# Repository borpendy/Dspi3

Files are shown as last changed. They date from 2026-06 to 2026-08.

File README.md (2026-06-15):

# DSpi3
<div align="center">
  Lower DSpi
</div>

# System overview
The DSpi3 is the 3rd generation of the DS-pi project, a project with the goal of creating an open source dual screen gaming handheld, aimed at DS and 3DS emulation. This iteration features a full outer redesign, with significant reductions in width, as well as a fully redesigned cooling system. The screen configuration has also been upgraded again, now featuring dual 720p displays.

# Emulation capabilities
System performance is as expected from a standard raspberry pi 5. The system should be able to confortably emulate DS, PS1, PSP and any systems below that. I have also had good results with 3ds emulation, using the Borked3DS emulator, and some light PS2 and GC games may be playable. Regular steam also works, using the box86 and wine translation layers, however the number of playable games is limited. Streaming games should also be possible via steam-link or any other streaming methods.

# System Specifications

- Uses any Pi CM5 module (however the CM5 lite 8GB wifi is highly recommended) with 4 A76 cores at 2.4GHz.
- Duak 1280x720 5 inch displays, with capacitive touch on both screens.
- Stereo speakers, using PCM5102 DAC + NS4150B amplifier, over the I2S interface.
- Headphone output, sharing the same PCM5102 DAC + PAM8908 Headphone AMP, speaker muting is enabled through the 3.5mm jack.
- 5000 Mah LiPo battery, with USB-PD charging enabled using the BQ24192 1S BMS, and HUSB238 PD controller..
- Full size controller using RP2040, and the GP2040CE firmware, using dual analog 3ds slide pads.
- Full 3d printable chassis, with both FDM and resin options available, using GBA SP hinges.

In addition to the changes in spec, this generation has also undergone a complete redesign of the internal electronics, to make use of the Modu-PI motherboard, more information here: https://github.com/borpendy/Modu-PI. This allows for a degree of seperation between the main motherboard, and controller daughterboard. If anyone wants to have a shot at improving the controller board (IMU, RGB ect), this should make things way easier for you.

## Other notes
Again this project is experimental, and not all things will work perfectly. This project has been an interesing journey, but unless you really want a linux handheld, I would suggest buying a current android handheld. If you are interested in how these devices are designed however, I encourage you check out the schematics above. Most of all, this has been fun, and its cool to have total freedom to design something yourself, and if you're thinking about doing someting similar, I highly recommend the experience.

Note: This ones internally very similar to the dspi 2 so I reused some of the description :)

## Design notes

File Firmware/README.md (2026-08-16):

# Board firmware
The DSPI motherboard requires programming of the onboard stm32 microcontroller before use. This can be done using any ST-LINK programmer, and the provided programming pins on the motherboard.\
\
To program the board, download the STM32CUBE project file above and run with the board connected through the ST-LINK as below:

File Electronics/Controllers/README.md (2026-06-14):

# Custom Controllers
These are based on the GP2040CE advanced breakout, and use the GP2040CE firmware. To program the boards, follow the GP2040CE installation instructions. The controller is connected to the motherboard over a standard usb interface, and should act as a standard usb controller.

Note for ordering: The impedance requirements for the pcb should be fairly loose, but to be safe I recommend using the JLC 7628 stackup when ordering the boards.

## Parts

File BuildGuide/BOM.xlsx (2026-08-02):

Part | Part name | Price | Sourcing
Main screen | Waveshare 5-DSI-TOUCH-A | 52.7 | https://www.waveshare.com/5-dsi-touch-a.htm
Secondary screen | Waveshare 5-DSI-TOUCH-A | 53.7 | https://www.waveshare.com/5-dsi-touch-a.htm
Raspberry pi cm5 | SC1598 (8GB lite wireless) | 276 | https://www.digikey.com.au/en/products/detail/raspberry-pi/SC1598/25805587
Battery | 955565 LIPO | 9 | https://www.amazon.com.au/dp/B0BG82T39Y
Fan | Rasberry pi blower 30x30x7 | 5 | https://www.aliexpress.com/item/1005006547048892.html
Heatsink | Aluminium Heatsink for CM4 | 5 | https://www.waveshare.com/cm4-heatsink.htm
Motherboard | Custom build - JLCPCB | ??? | https://github.com/borpendy/Dspi3
Controller Left | Custom build - JLCPCB | ??? | https://github.com/borpendy/Dspi3
Controller Right | Custom build - JLCPCB | ??? | https://github.com/borpendy/Dspi3
Thumbstick x2 | 3DS slidepad | 12x2 | https://www.aliexpress.com/item/1005005449043551.html
mobo to controller cable | 100mm 22p dsi ribbon cable (forward direction) | 7 | https://www.aliexpress.com/item/1005006608534110.html
controller interconnect cable | 150mm 22p dsi ribbon cable (forward direction) | 7 | https://www.aliexpress.com/item/1005006608534110.html
screen 1 cable | 100mm 22p dsi cable (reverse) (comes with screen) | 0 | N/A
screen 2 cable | 300mm 22p dsi cable (reverse) | 10 | https://www.aliexpress.com/item/1005006608534110.html
Screens power cable | Custom (need 2p jst ph2.0 cable) | 3 | https://www.aliexpress.com/item/1005007617385129.html
face buttons (if installing by self) | 6x6x3.1mm push button red | 5 | https://www.aliexpress.com/item/1005008012010102.html
back buttons (if installing by self) | 6x6x4.3mm push button right angle | 2 | https://www.aliexpress.com/item/1005010093330224.html
Any sd card
Speakers x2 | SP-1605 | 7 | https://www.digikey.com.au/en/products/detail/soberton-inc/SP-1605/3973691
Speaker wires | jst sur 2p 0.8mm 200mm | 3 | https://www.aliexpress.com/item/1005009264311917.html
Screw kit machine screws |  |  | https://www.amazon.com.au/dp/B0B394XZD3
Screw kit self taping |  |  | https://www.amazon.com.au/dp/B0D4QLWSBK
Jst connector right angle | Right-Angle JST Socket Male Connector |  | https://www.aliexpress.com/item/33053313994.html

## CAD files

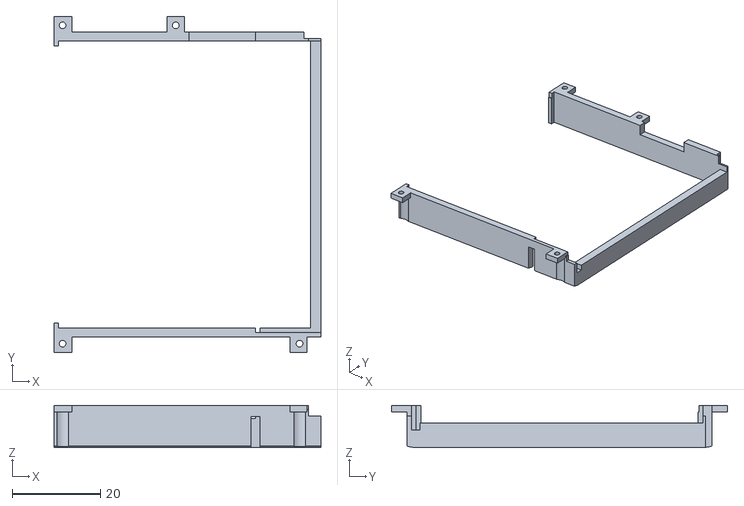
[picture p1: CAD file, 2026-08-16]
Print files/BodyParts/battery holder.stl
60.3 x 76.0 x 9.50

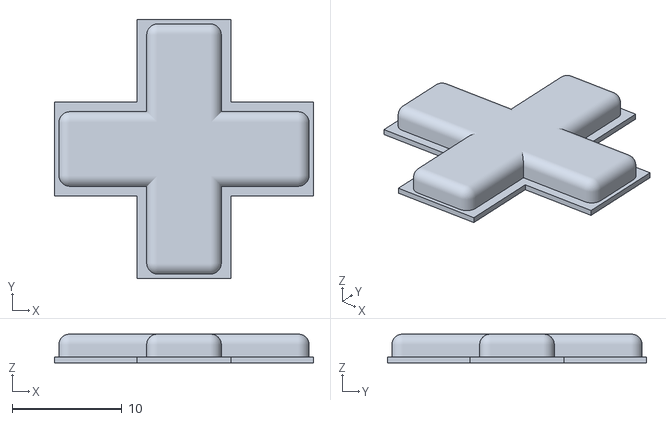
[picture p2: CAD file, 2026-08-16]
Print files/Buttons/dpad.stl
23.6 x 23.6 x 2.61

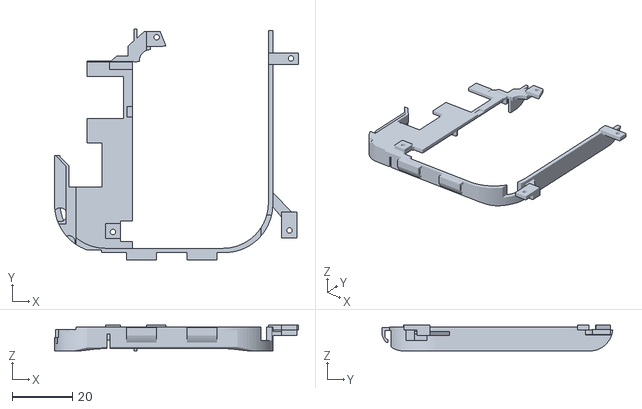
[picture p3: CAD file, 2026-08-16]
Print files/BodyParts/fan mount.stl
80.8 x 76.4 x 8.60

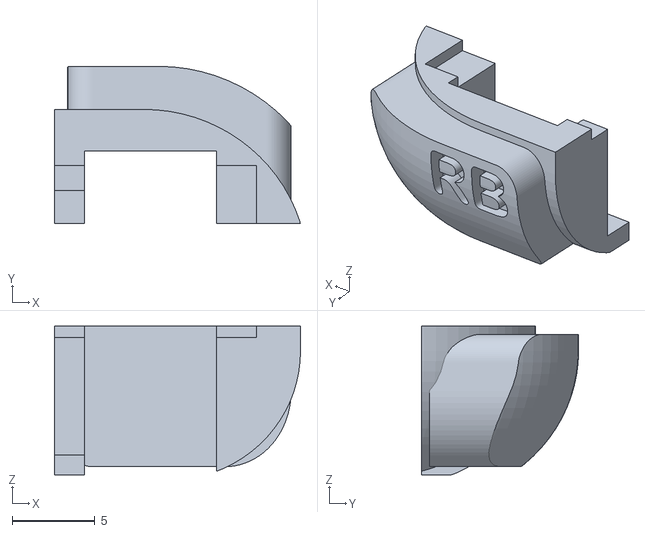
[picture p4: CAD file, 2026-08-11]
Print files/Buttons/RB.stl
14.9 x 9.50 x 9.00

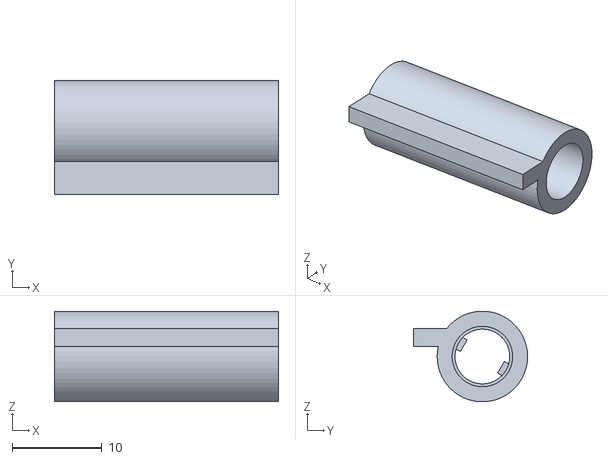
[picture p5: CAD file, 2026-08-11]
Print files/BodyParts/hinge_r_outer.stl
25.0 x 12.7 x 10.1

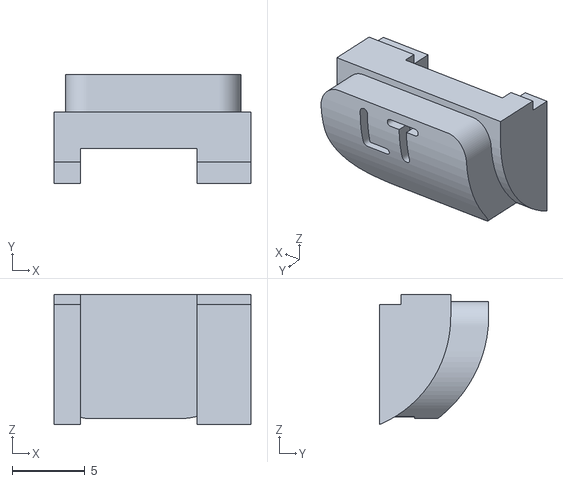
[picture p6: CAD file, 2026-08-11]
Print files/Buttons/LT.stl
13.5 x 7.50 x 8.92

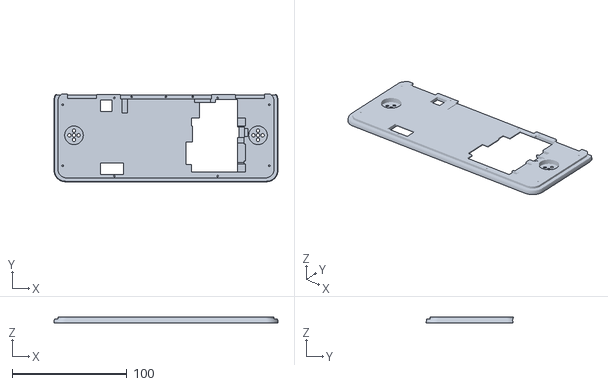
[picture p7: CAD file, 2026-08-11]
Print files/BodyParts/top plate.stl
195.0 x 76.3 x 5.40

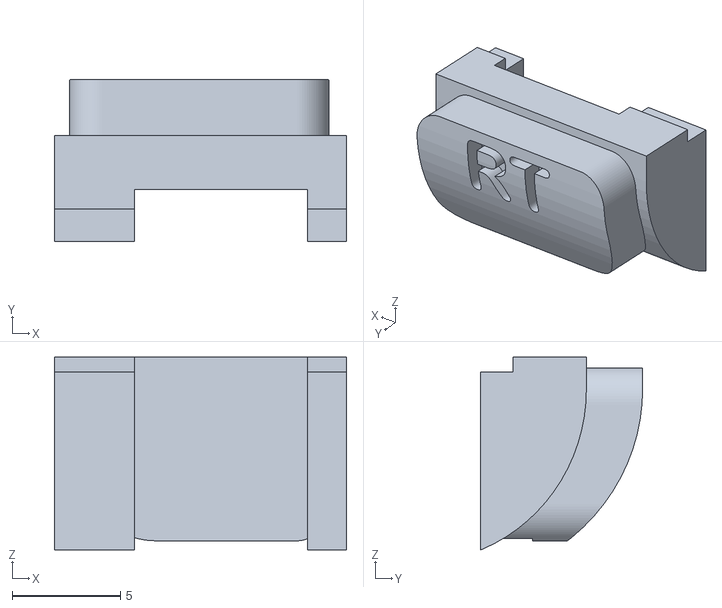
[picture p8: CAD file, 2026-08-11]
Print files/Buttons/RT.stl
13.5 x 7.50 x 8.92

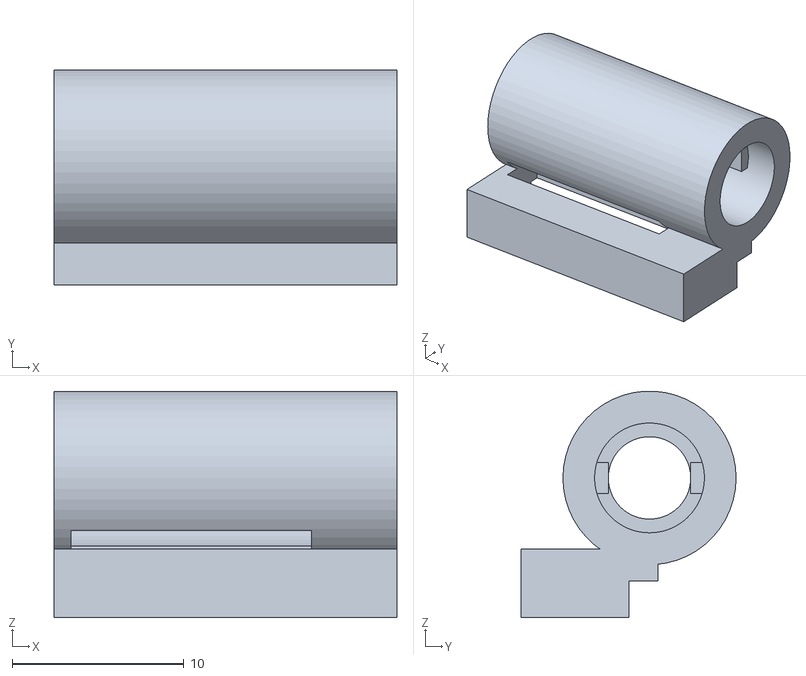
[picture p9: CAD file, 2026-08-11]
Print files/BodyParts/hinge_r_inner.stl
20.0 x 12.6 x 13.2

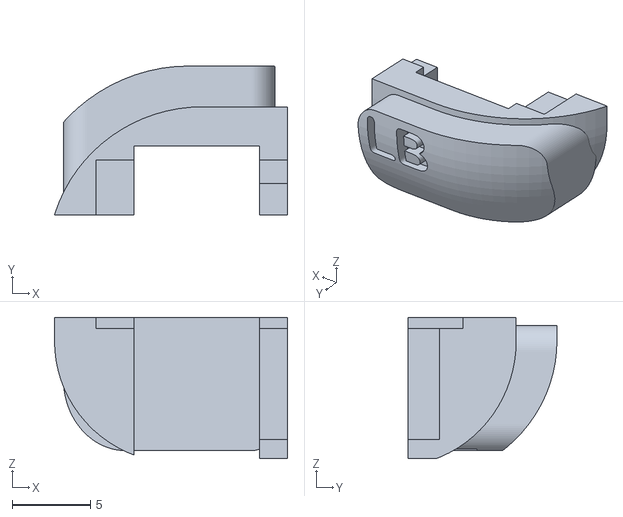
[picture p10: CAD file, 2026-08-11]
Print files/Buttons/LB.stl
14.9 x 9.50 x 9.00

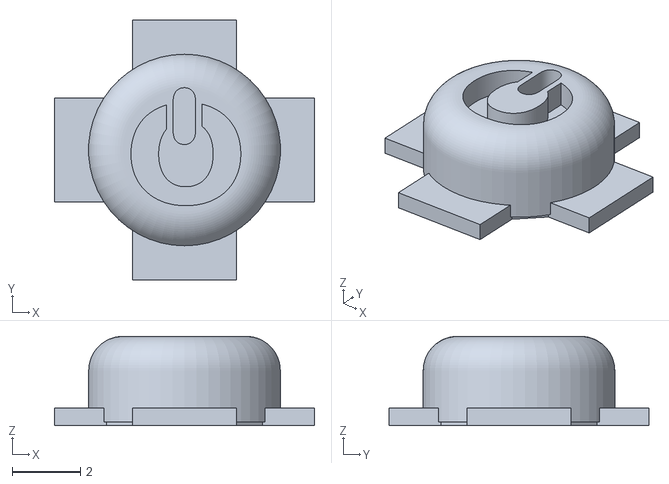
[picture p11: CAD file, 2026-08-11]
Print files/Buttons/PWR.stl
7.60 x 7.60 x 2.61

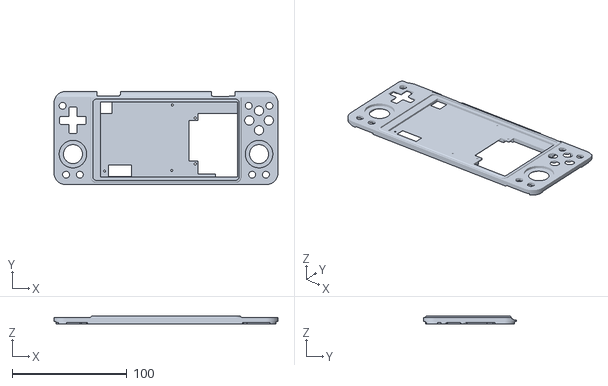
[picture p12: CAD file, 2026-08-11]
Print files/BodyParts/bottom plate.stl
195.0 x 81.0 x 6.73

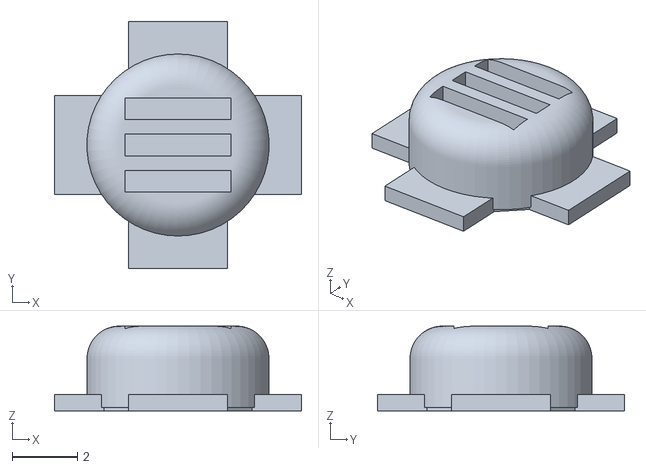
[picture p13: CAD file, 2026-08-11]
Print files/Buttons/SELECT.stl
7.60 x 7.60 x 2.61

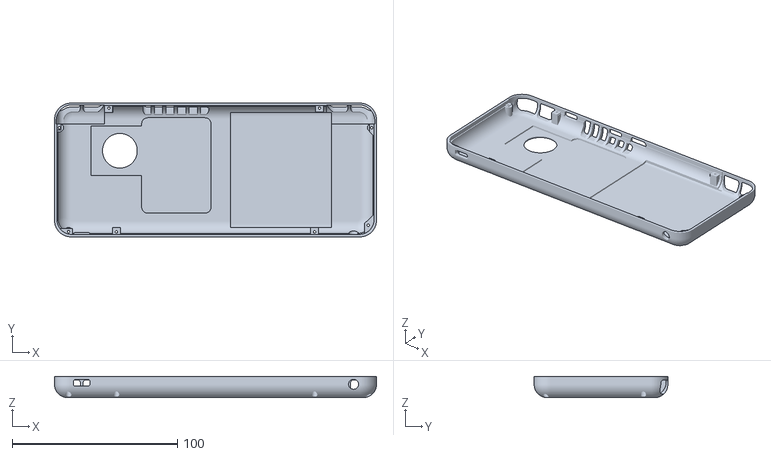
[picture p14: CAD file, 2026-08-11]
Print files/BodyParts/bottom cover.stl
195.0 x 81.0 x 12.9

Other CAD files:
Print files/BodyParts/hinge_l_outer.stl
Print files/Buttons/START.stl
Print files/BodyParts/top cover.stl
Print files/Buttons/A.stl
Print files/BodyParts/hinge_l_inner.stl
Print files/BodyParts/hinge_m.stl
Print files/Buttons/B.stl
Print files/Buttons/LS.stl
Print files/Buttons/X.stl
Print files/Buttons/Y.stl
dspi final.blend

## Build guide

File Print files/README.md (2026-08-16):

# Print parts
You can find all the stl's required to print your own parts here. Note that there are seperate shell files for resin and filament printers. This is as the hinge parts must be printed seperatly using filament, to maintain acceptable strength and dimensional accuracy. 
The internal parts may be printed in resin or fdm. I personally prefer fdm for the holders, and resin for the buttons.

When printing make sure you scale appropriately for the material used, I had good results using 100.3% scale for pla. Also scale all buttons at 98% before printing.

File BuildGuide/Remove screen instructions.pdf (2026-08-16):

## How to remove Waveshare 5 inch screen from enclosure:

Step 1: Get a hotplate/FDM printer plate, set the plate temp to 80 degrees Celsius and place the screen face down on the plate. Make sure the screws on the back of the screen case have been removed:

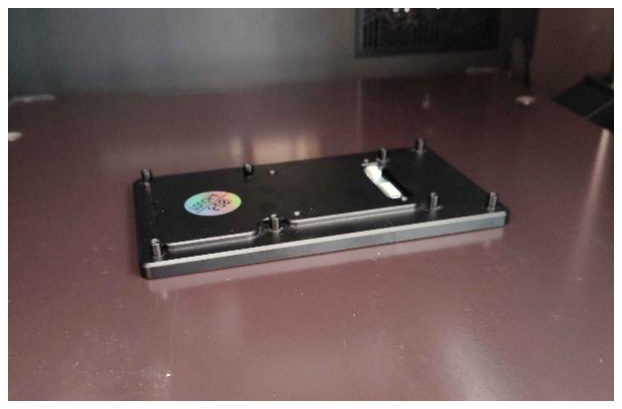
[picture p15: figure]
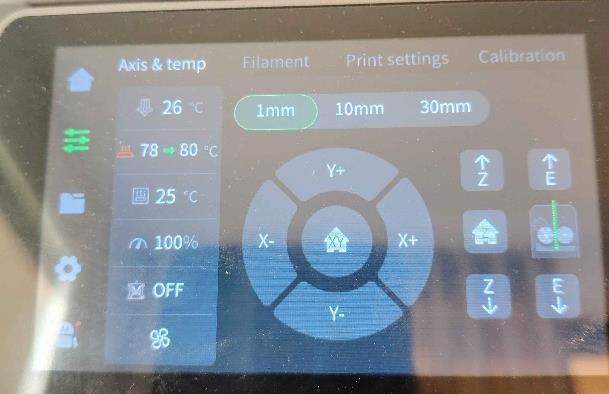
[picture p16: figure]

Step 2: Once the back of the screen feels hot, remove the screen and push it from behind, just above the power and data connectors, using your fingers.

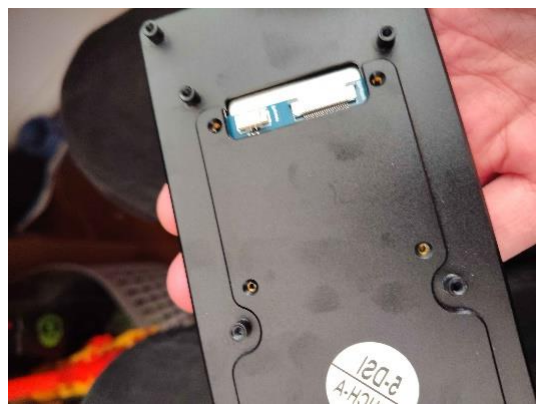
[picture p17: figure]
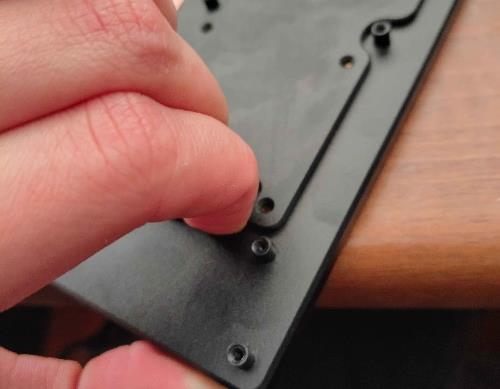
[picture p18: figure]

Step 3: If done correctly, there should now be a small gap at the edge of the screen when pushing. Put either your nail or a small plastic shim in here and push it lengthways to widen the gap. Move around the edge of the screen and it should eventually come out:

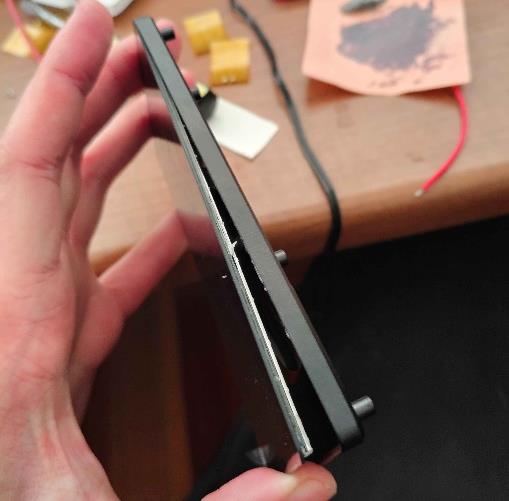
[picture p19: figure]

Authors note: This step is really annoying, and this process is probably the hardest part of the build. If anyone finds a better way to do this, please let me know.

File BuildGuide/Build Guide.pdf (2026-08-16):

# DSpi3 Build guide

By William Oprey :)

Please note:
This is an intermediate to difficult level project. To build this, you must know how to solder at minimum, and there is some fiddly work that may be difficult for some people. You also need either an FDM or Resin printer to produce parts, and having an FDM printer is useful for the screen removal as well.
I haven’t included any instructions for this, but I highly recommend some post processing + painting of the main parts before assembly, as it looks quite nice.

Parts list:
Part | Quantity
RasPI 5 Compute module lite | 1
DSPI Motherboard | 1
DSPI Left controller board | 1
DSPI Right controller board | 1
Bottom Plate Print | 1
Bottom Cover Print | 1
Lower Hinge Right Print | 1
Lower Hinge Left Print | 1
Lower Hinge Middle Print | 1
Fan Guide Print | 1
Battery Holder Print | 1
Top Plate Print | 1
Top Cover Print | 1
Top Hinge Left Print | 1
Top Hinge Right Print | 1
PCB Inserts Print | 1
Buttons Prints | 1
Waveshare 5 -DSI -TOUCH -A screen | 2
GBA SP Hinge | 2
Soberton SP -1605 Speakers | 2
3DS Thumbstick (inc cap) | 2
Raspberry pi 5 fan 30x30 | 1
Pi CM5 low -profile heatsink | 1
5000maH 955565 LiPo battery | 1
15cm 22p same side ribbon cable | 1
30cm 22p opposite side ribbon cable | 1
10cm 22p same side ribbon cable | 1
10cm 22p opposite side ribbon cable | 1
JST PH 2.0 2p cable | 2
JST PH 1.25 2p cable | 2
JST SUR 0.8 2p cable | 2
M1.7x4 machine screw | 20
M1.7x8 self -taping screw | 4
M1.7x3 machine screw | 11
M2x5 machine screw | 4
6x6x3.1 tactile pushbutton | 15
JST 2.0 header right angle | 2

Build steps:
Step 1:
Apply super glue to the hinge cutouts on the top and bottom plates, then attach the outer and inner hinges to their respective plates:
Step 2:

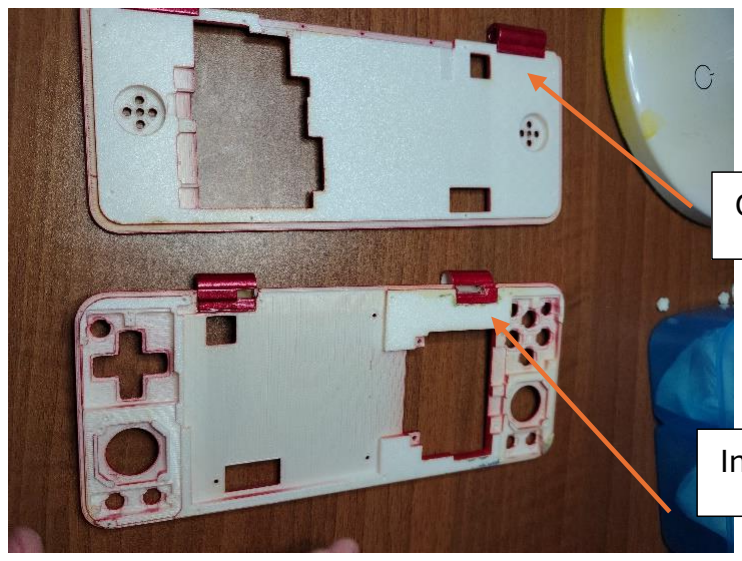
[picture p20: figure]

Remove the screens from the metal enclosures they come in, steps for this are in a separate file on the GitHub
Step 3:
Insert the screens into the top and bottom plates, then apply hot glue into the cutouts provided. Ensure the hot glue does not protrude out from the plate, so the pcbs mount correctly later.
Step 4:

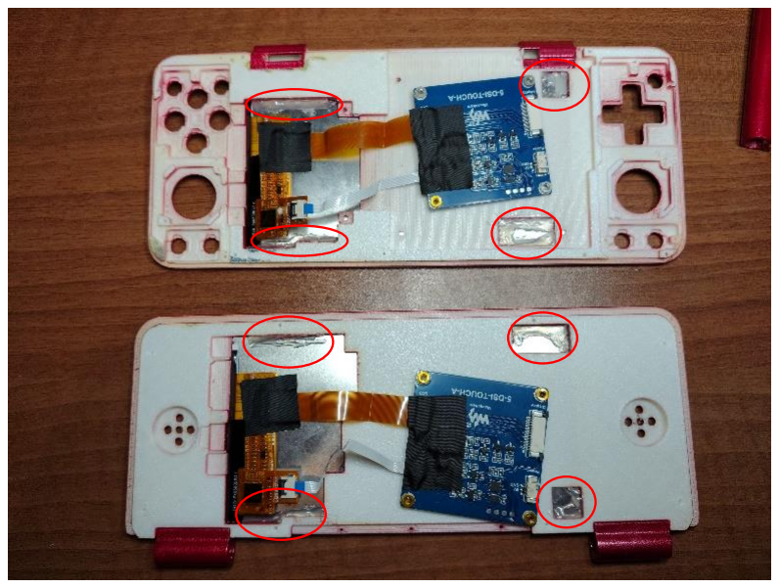
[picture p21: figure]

Insert the GBA hinges into the outer hinge on the top plate. Ensuring the hinge is aligned to the guides in the body, such as in the image below:

Outer hinges

Inner hinges

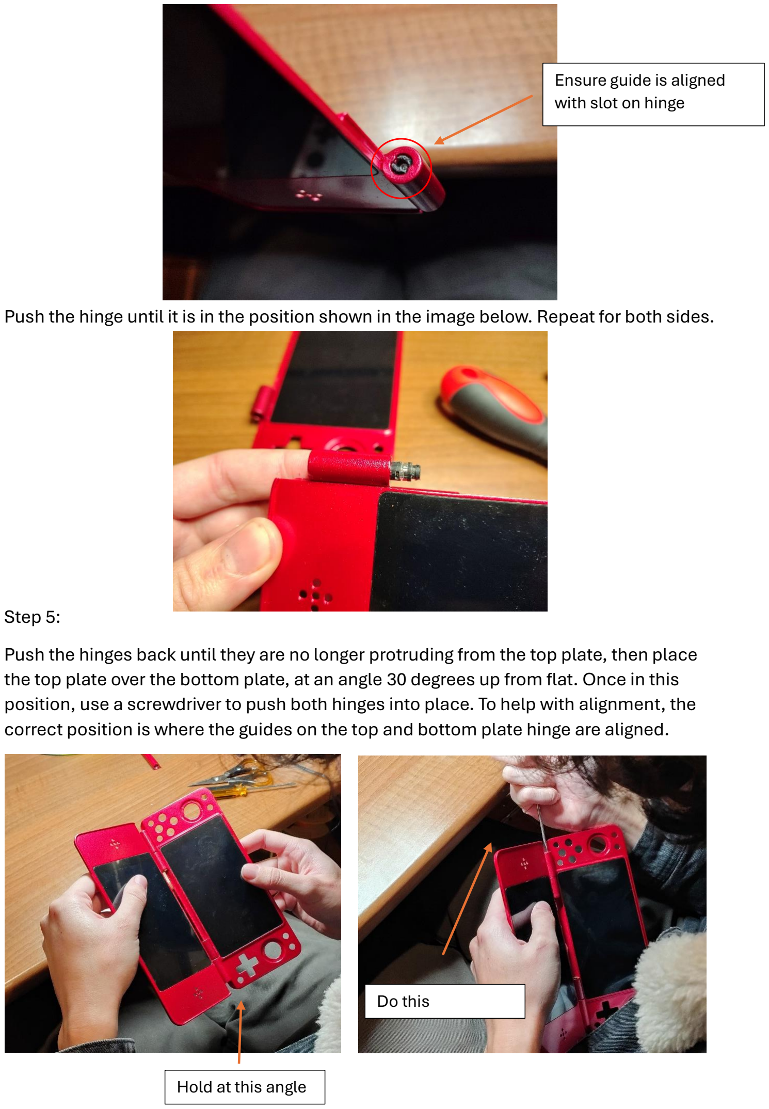
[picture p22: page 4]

Push the hinge until it is in the position shown in the image below. Repeat for both sides.

Step 5:
Push the hinges back until they are no longer protruding from the top plate, then place the top plate over the bottom plate, at an angle 30 degrees up from flat. Once in this position, use a screwdriver to push both hinges into place. To help with alignment, the correct position is where the guides on the top and bottom plate hinge are aligned.

Ensure guide is aligned
with slot on hinge

Hold at this angle

Do this

Step 5:
Secure the screen PCB to the bottom plate using the original screws from the screen case. Only screw in the screws shown in the picture below.
Step 6:

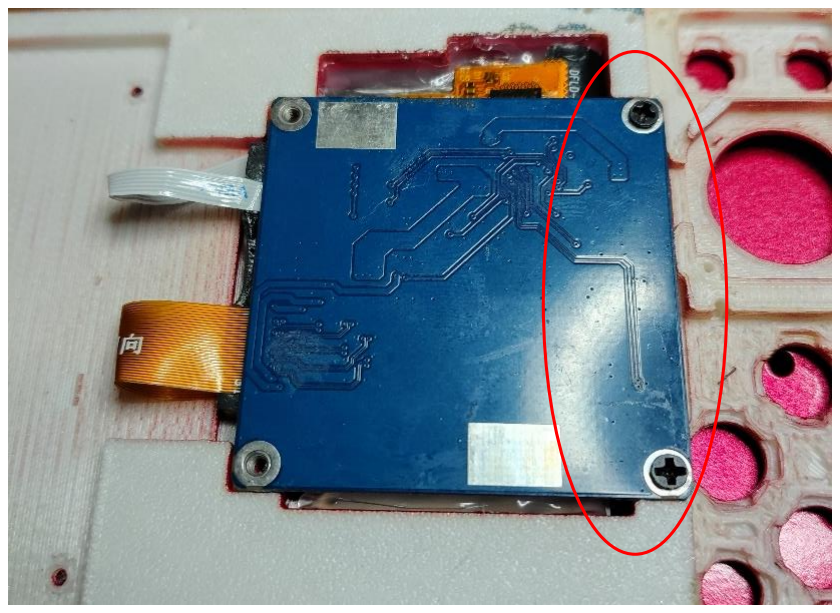
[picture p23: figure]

Get the screen PCB inserts (3D Print) and place them over the standoffs on the upper screen PCB. Place the PCB over the top plate with inserts in the provided slots, then superglue the inserts into place.

Step 7:

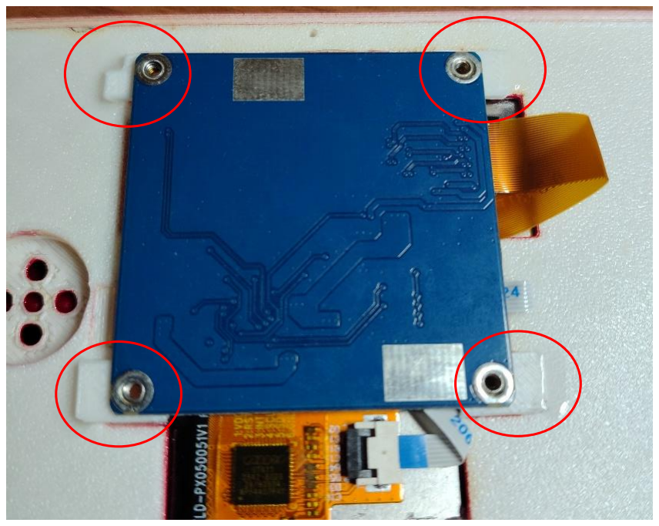
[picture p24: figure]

Place the front facing buttons into the plate. Ensure that all buttons go fully into place, if any get stuck before this you may have to use a screwdriver to clear out the button guide tabs.

Step 8:

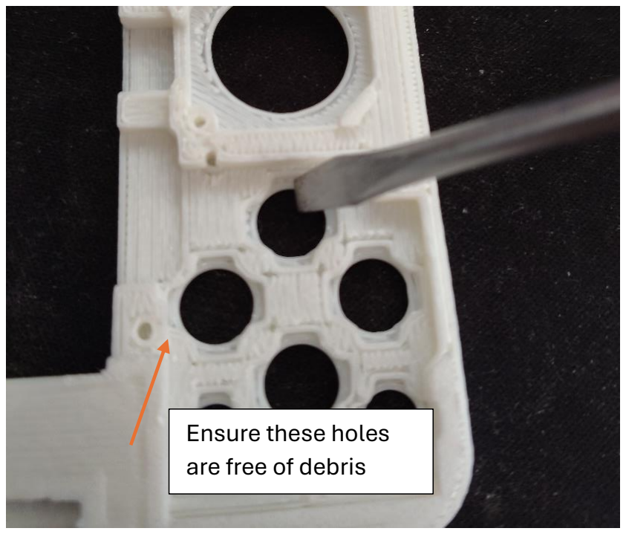
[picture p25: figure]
Ensure these holes are free of debris

Solder the buttons to the controller PCBs. Ensure that you solder the bumper buttons first, then use clippers to remove any protruding pins, before soldering the face buttons.
Step 9:
Screw in the left and right controller PCBs to the bottom plate. Test all the buttons once PCBs are inserted, there should be a click sound and feel. Insert the thumb stick FPC cables into their connectors and screw the thumb sticks to the plate. Connect the PCBs together using a 22p 15cm same side ribbon cable.
Use m1.7x4 machine screws for the PCBs and m1.7x8 self-taping screws for the sticks

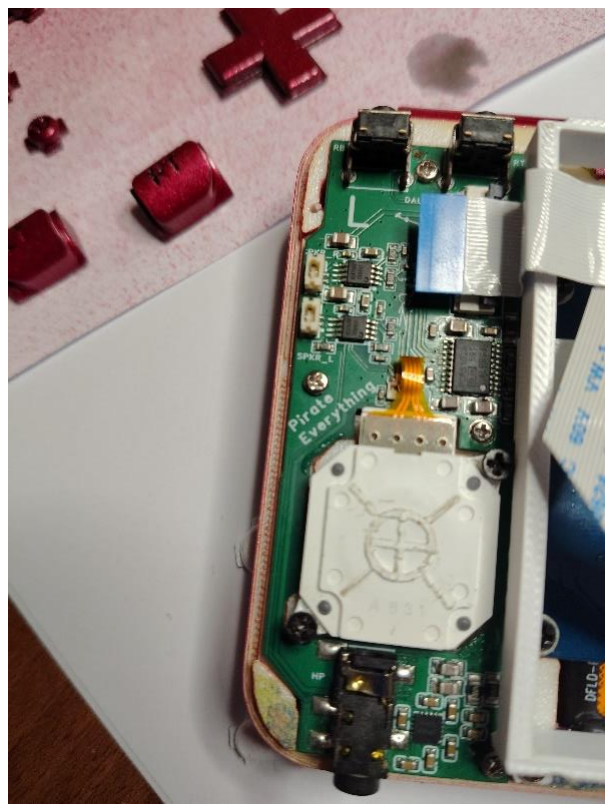
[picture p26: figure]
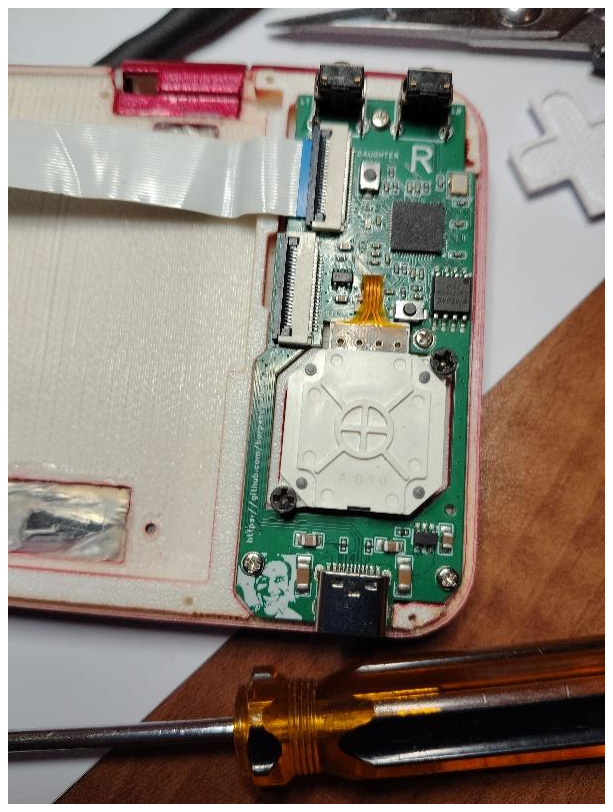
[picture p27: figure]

Step 10:
Roll a 30cm 22p different side ribbon cable through the left hinge, using the provided hole. Ensure the orientation of the cable matches the one pictured

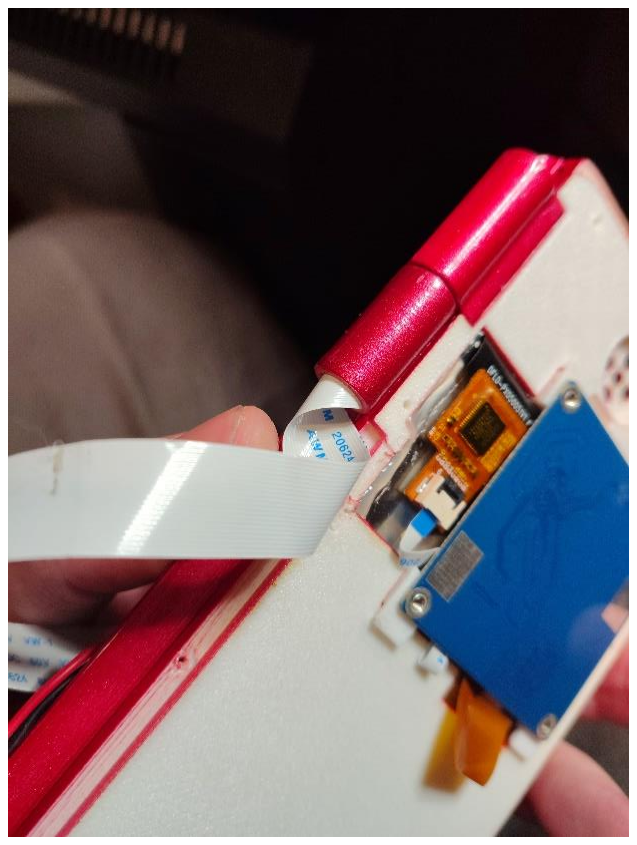
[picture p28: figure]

Step 11:

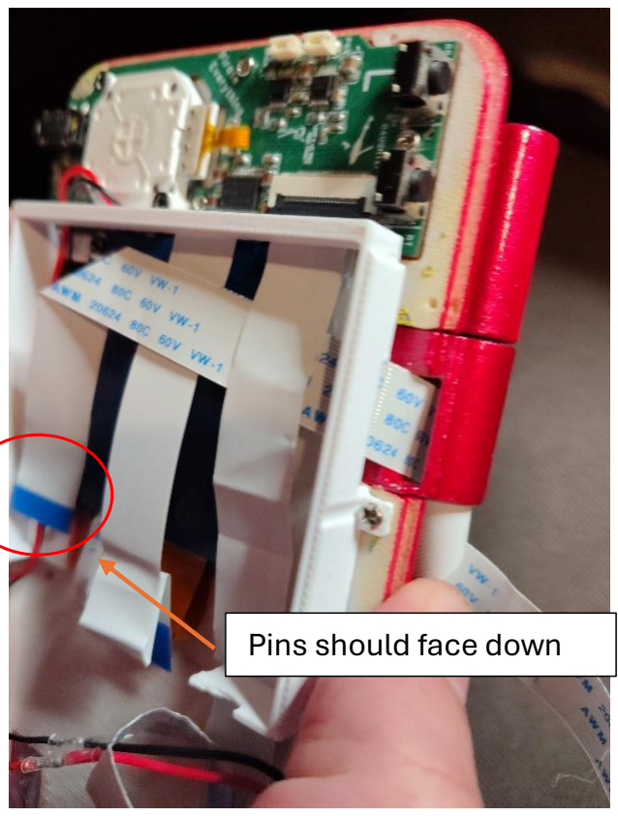
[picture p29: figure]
Pins should face down

Build the screen power cable to match the one pictured below. The cable is a jst2.5 to 2xmicro-jst1.25 y adapter. One side of the cable is 30cm, and the other is 10cm long. Use the micro jst cables provided with the screens.

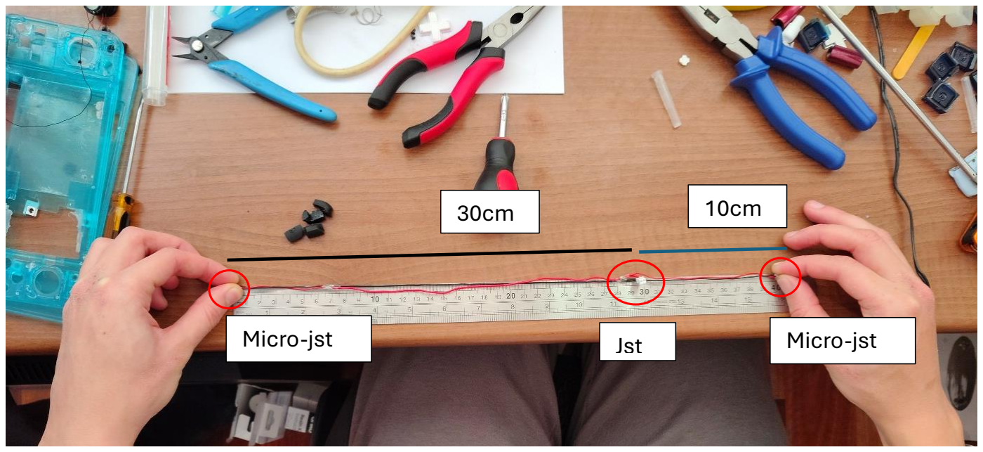
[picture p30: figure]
Micro; Jst -jst; Micro-jst

Step 12:
Build the speaker assembly by soldering the JST SUR 0.8 cables to the speakers. The left speaker wire length should be 24cm, and the right speaker wire length should be 30cm.

To achieve this, you may need to shorten the left wire and lengthen the right wire. Then, place the speakers into the top plate.

Step 13:

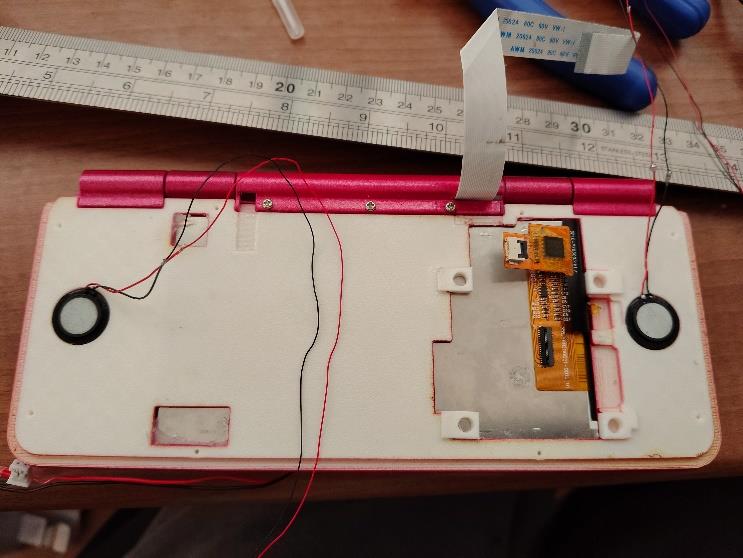
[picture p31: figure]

Roll the ribbon cable through the middle hinge segment, then screw the middle hinge into the top plate. Use m1.7x3 screws.

Step 14:

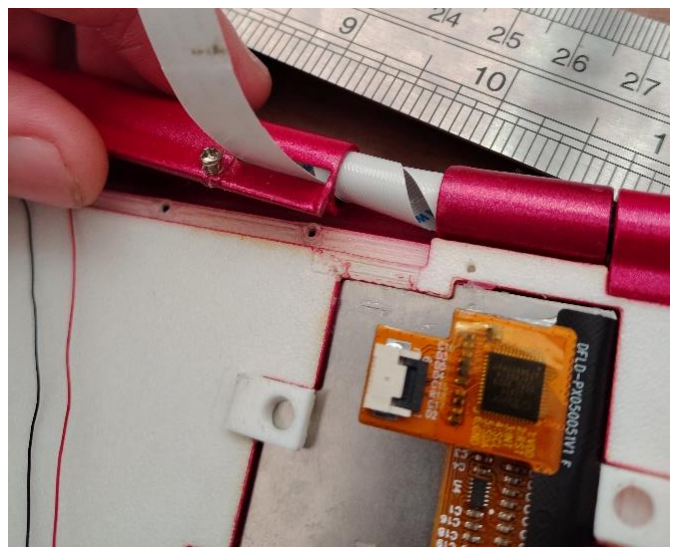
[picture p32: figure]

Run the longer end of the power cable though the provided hole on the left of the hinge, then run the speaker cables through the same hole.

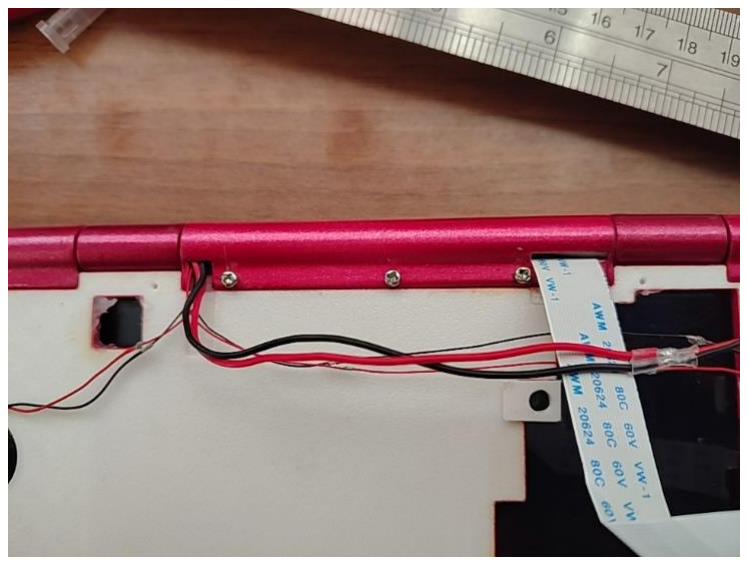
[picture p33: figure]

Step 15:
Connect the power and DSI ribbon cable to the upper screen PCB.
Step 16:
Solder the JST connectors for the battery and screens onto the DSpi motherboard. After soldering, trim off the pins on the bottom of the board.
Step 17:
Upload the firmware onto the DSpi motherboard using a st-link, and the programming pinholes on the board. Make sure the board is connected to power before programming. The firmware can be found in the GitHub page, use stm32cubeide to program.
Step 18:

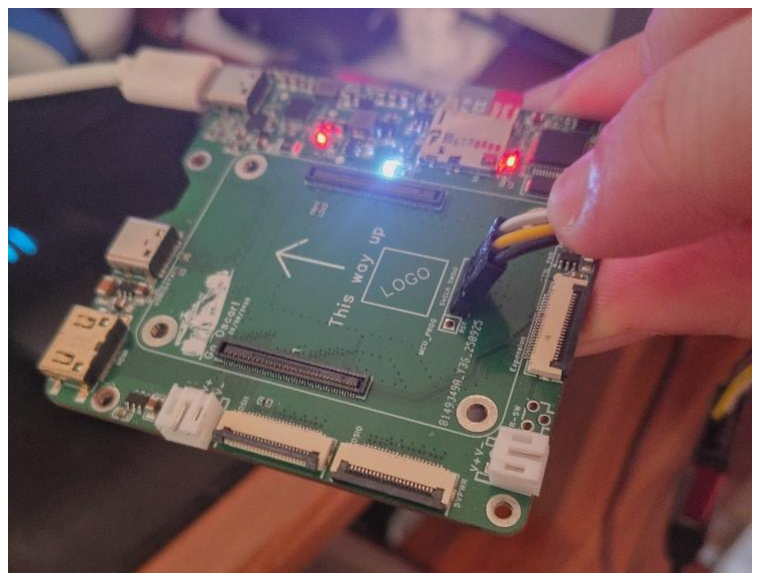
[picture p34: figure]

Apply thermal paste to the CPU on the compute module, then attach the heat sink. To reduce the height of the heatsink, mount it using the provided screws, as shown in the below image:

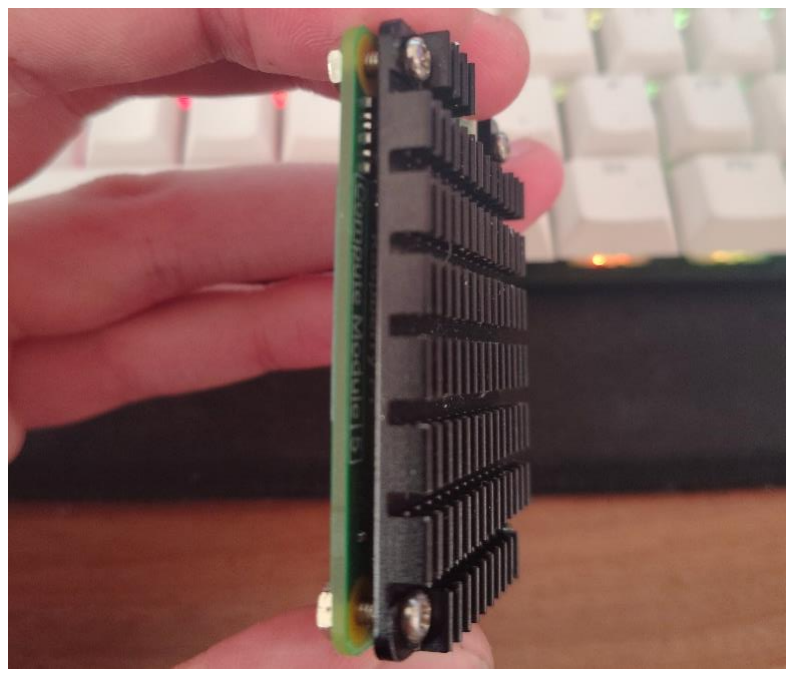
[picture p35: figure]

Step 19:
Superglue the cooling fan to the 3D printed fan guide. To ensure the fan cable can reach the motherboard, unclip the cable from the fan housing, and route it underneath the guide
Step 20:

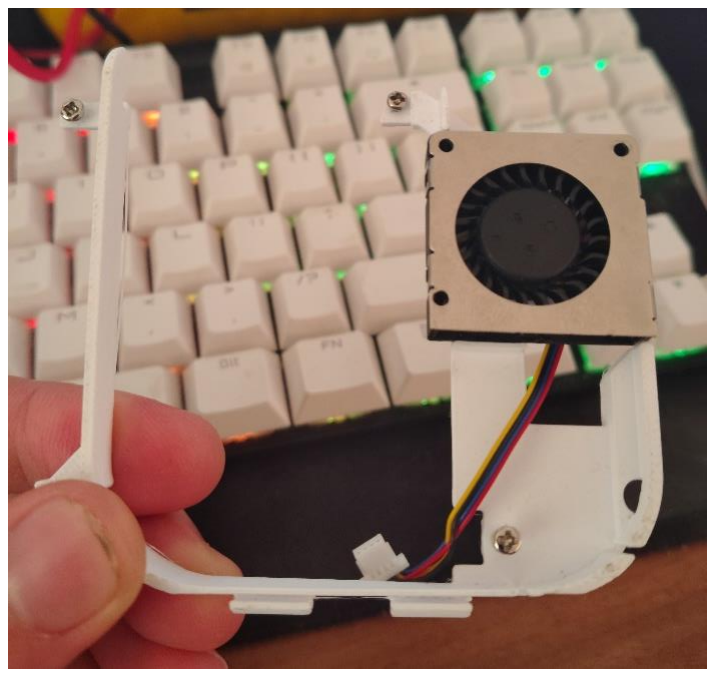
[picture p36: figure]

Program a SD card with the provided OS, or a fresh OS install, then insert the SD card into the motherboard.

Step 21:
Connect the motherboard to the right controller using a 10cm same side 22p ribbon cable.

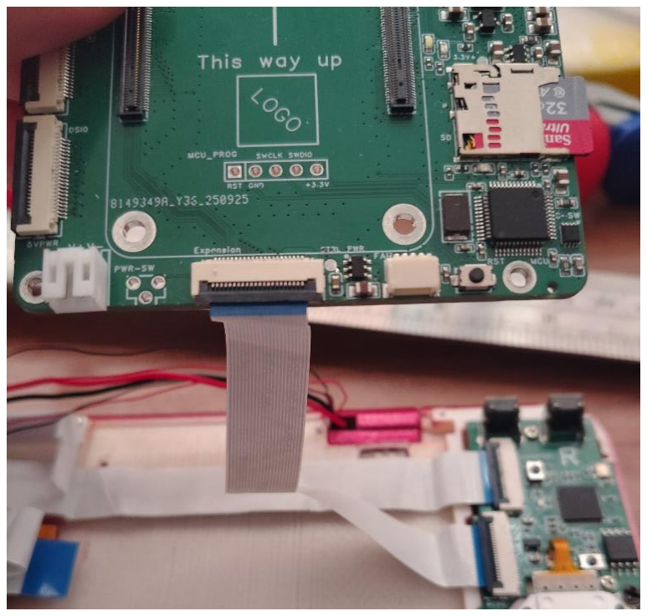
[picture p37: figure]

Step 22:
Place the motherboard on the bottom plate, making sure the power cable sits below in the provided hinge. Place the fan guide over the motherboard, then route the power cable through the clips, and plug it into the motherboard
Step 23:

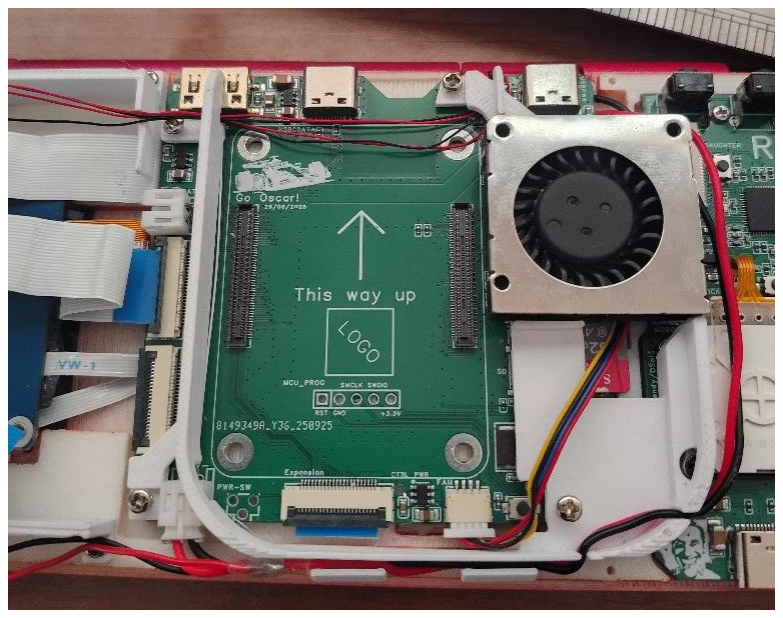
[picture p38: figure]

Screw in the motherboard to the bottom plate, making sure the screws go through the fan guide. Plug the compute module into the motherboard, making sure the antenna cutout is facing up (important).
Use m2x5 machine screws, and screw until you feel some resistance then stop (Important). This is to make sure you don’t screw into the screen.
Step 24:
Unscrew the bottom screen PCB, then plug in the power cable, and connect the display to the motherboard using a 10cm 22pin different side ribbon cable. Then re-attach the PCB.

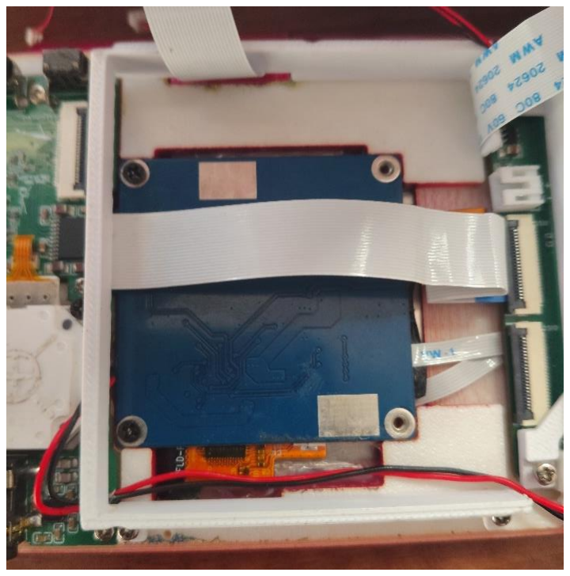
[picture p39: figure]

Step 25: Plug the speaker cables into the connectors on the left controller PCB.
Step 25:

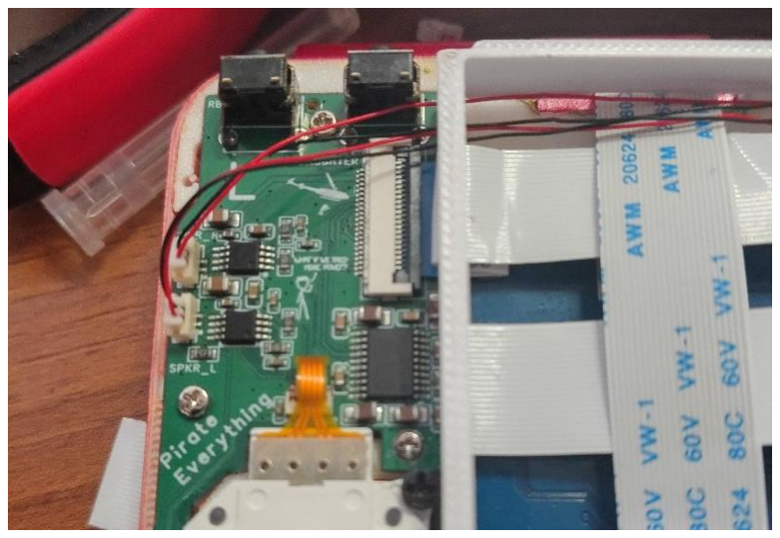
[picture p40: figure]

Screw the battery holder into the bottom plate, then place the battery into the holder and connect it to the motherboard. Check that the system runs (fan should start up), and that both screens display before continuing.
Use m1.7x4 machine screws.

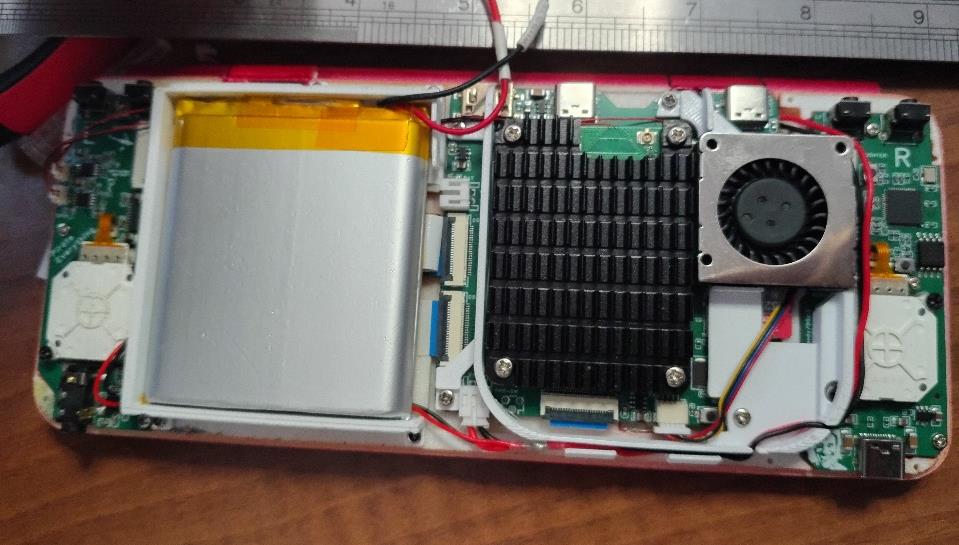
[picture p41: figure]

Fully assembled bottom end should look like this

Step 26:
Place the rear bumpers into the bottom cover, then attach the bottom shell and screw it in. Once finished, check that all the rear bumper buttons work (you should feel a click). Use m1.7x4 machine screws.
Step 27:

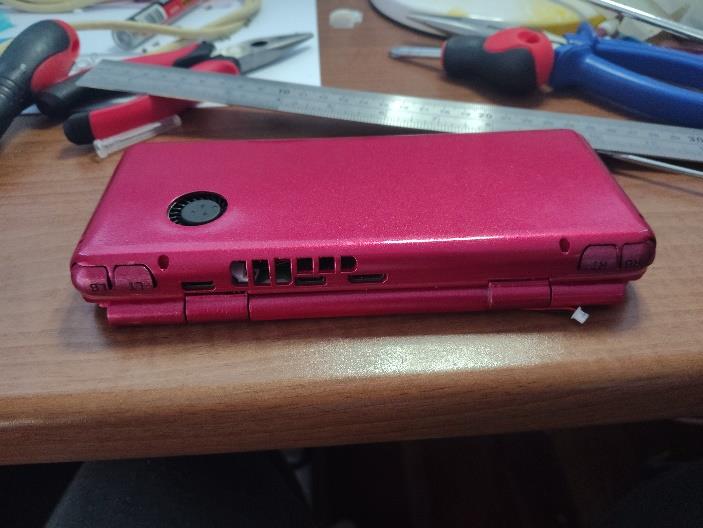
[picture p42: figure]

Screw in the top cover, making sure the top screen pcb is fully down
Use m1.7x3 machine screws.
Step 28: Follow the instructions on the GP2040-CE website to program the controller. Test that the controller works, and test that the speakers work.

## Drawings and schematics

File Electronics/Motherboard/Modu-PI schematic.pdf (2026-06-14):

CM5 CONNECTORS | USB

# DISPLAY - HDMI

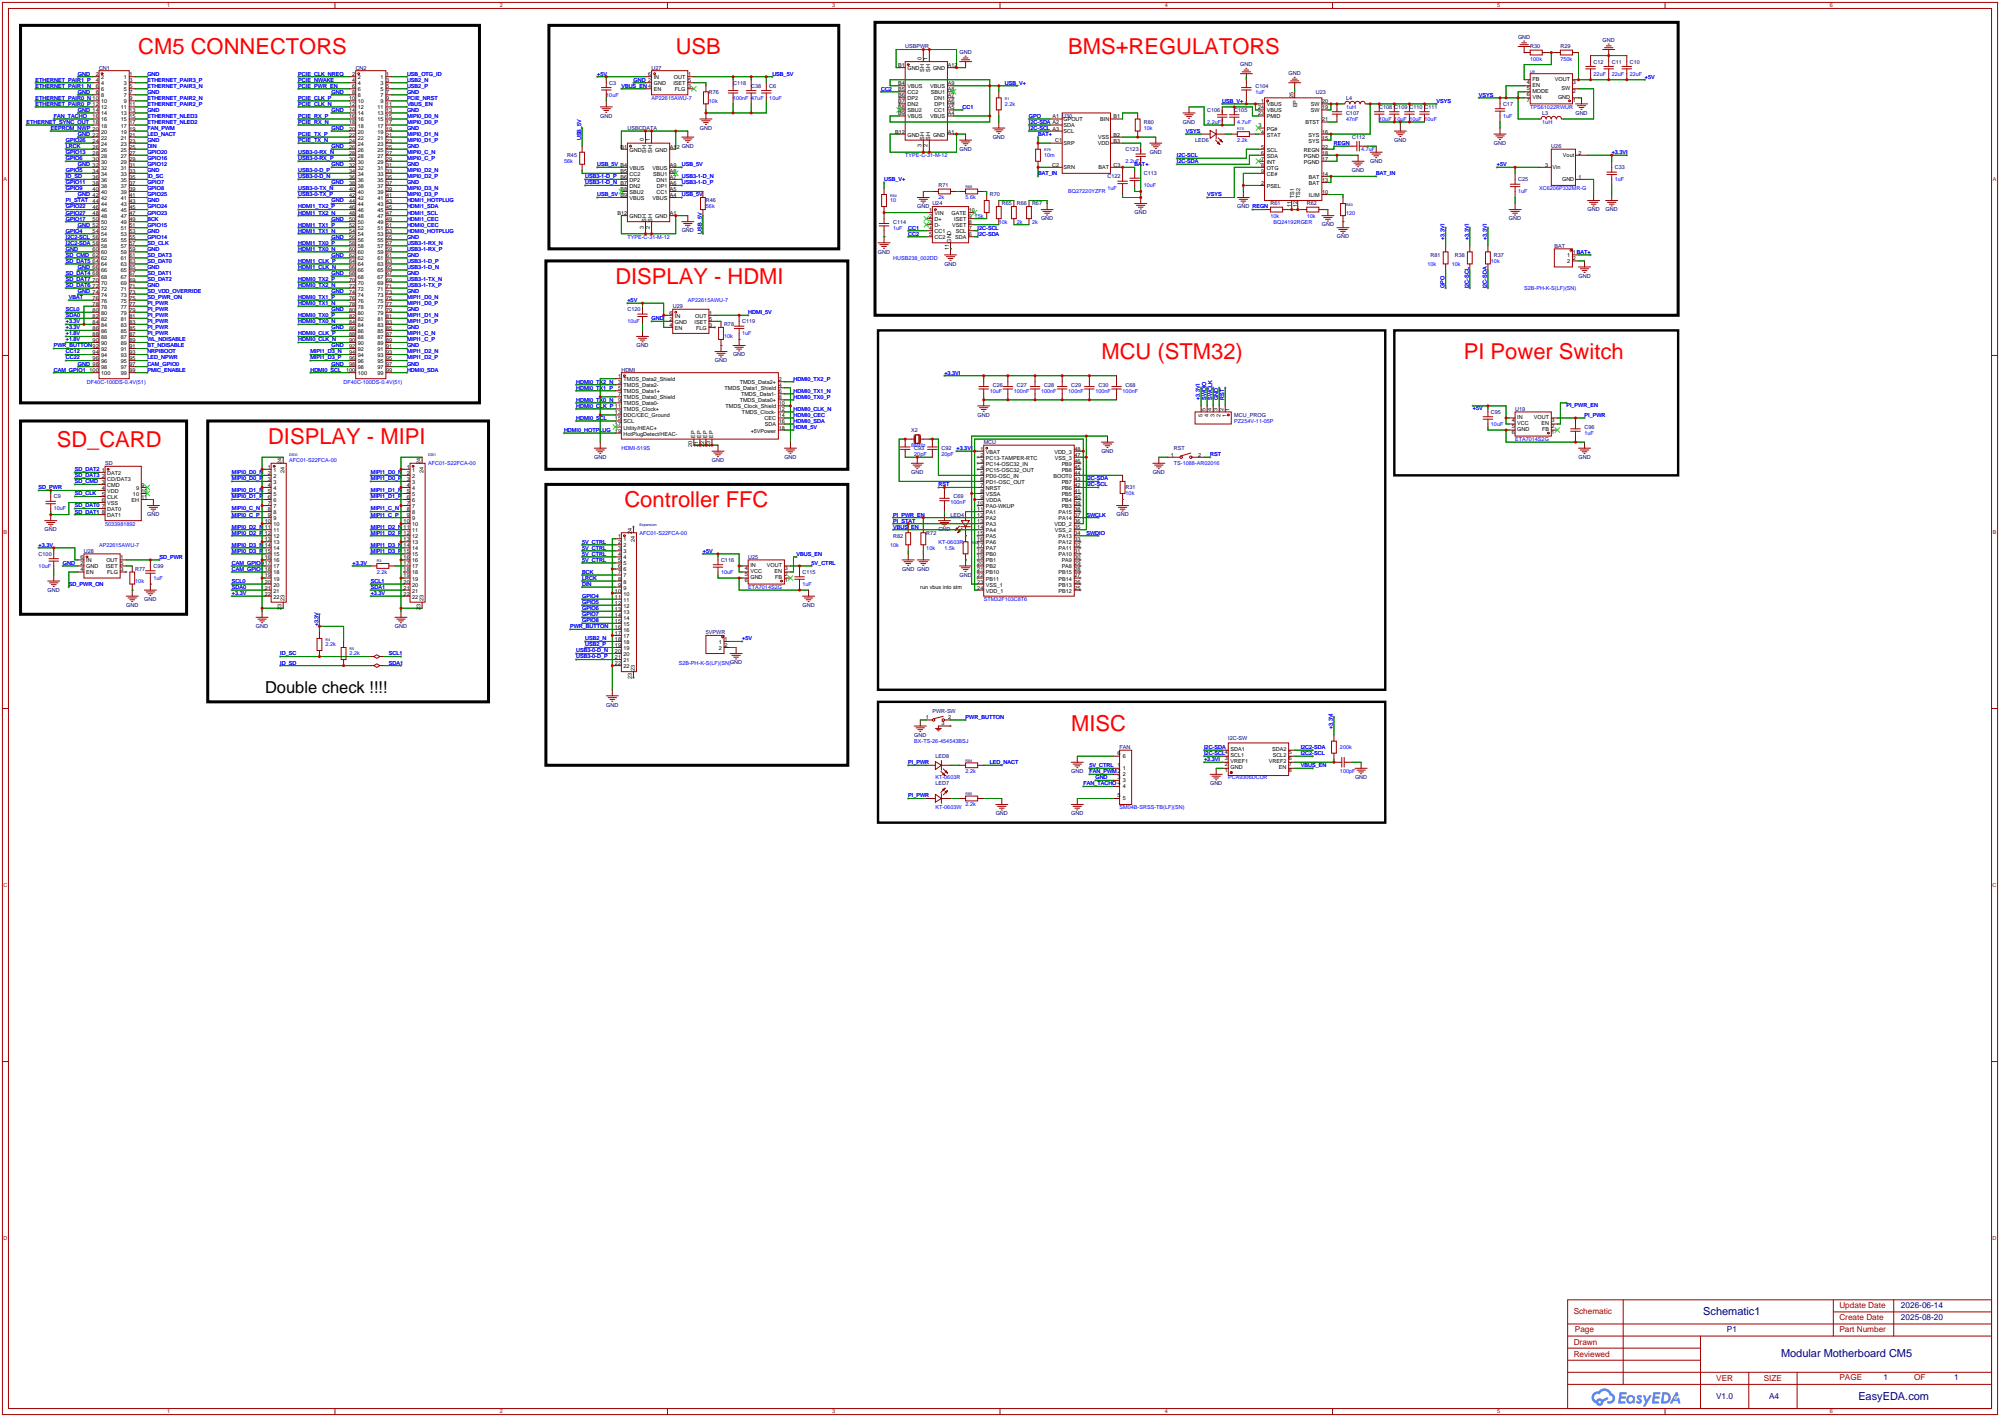
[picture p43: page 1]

Controller FFC

run vbus into stm

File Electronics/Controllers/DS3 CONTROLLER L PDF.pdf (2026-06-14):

# MISC

Analog | BUTTONS

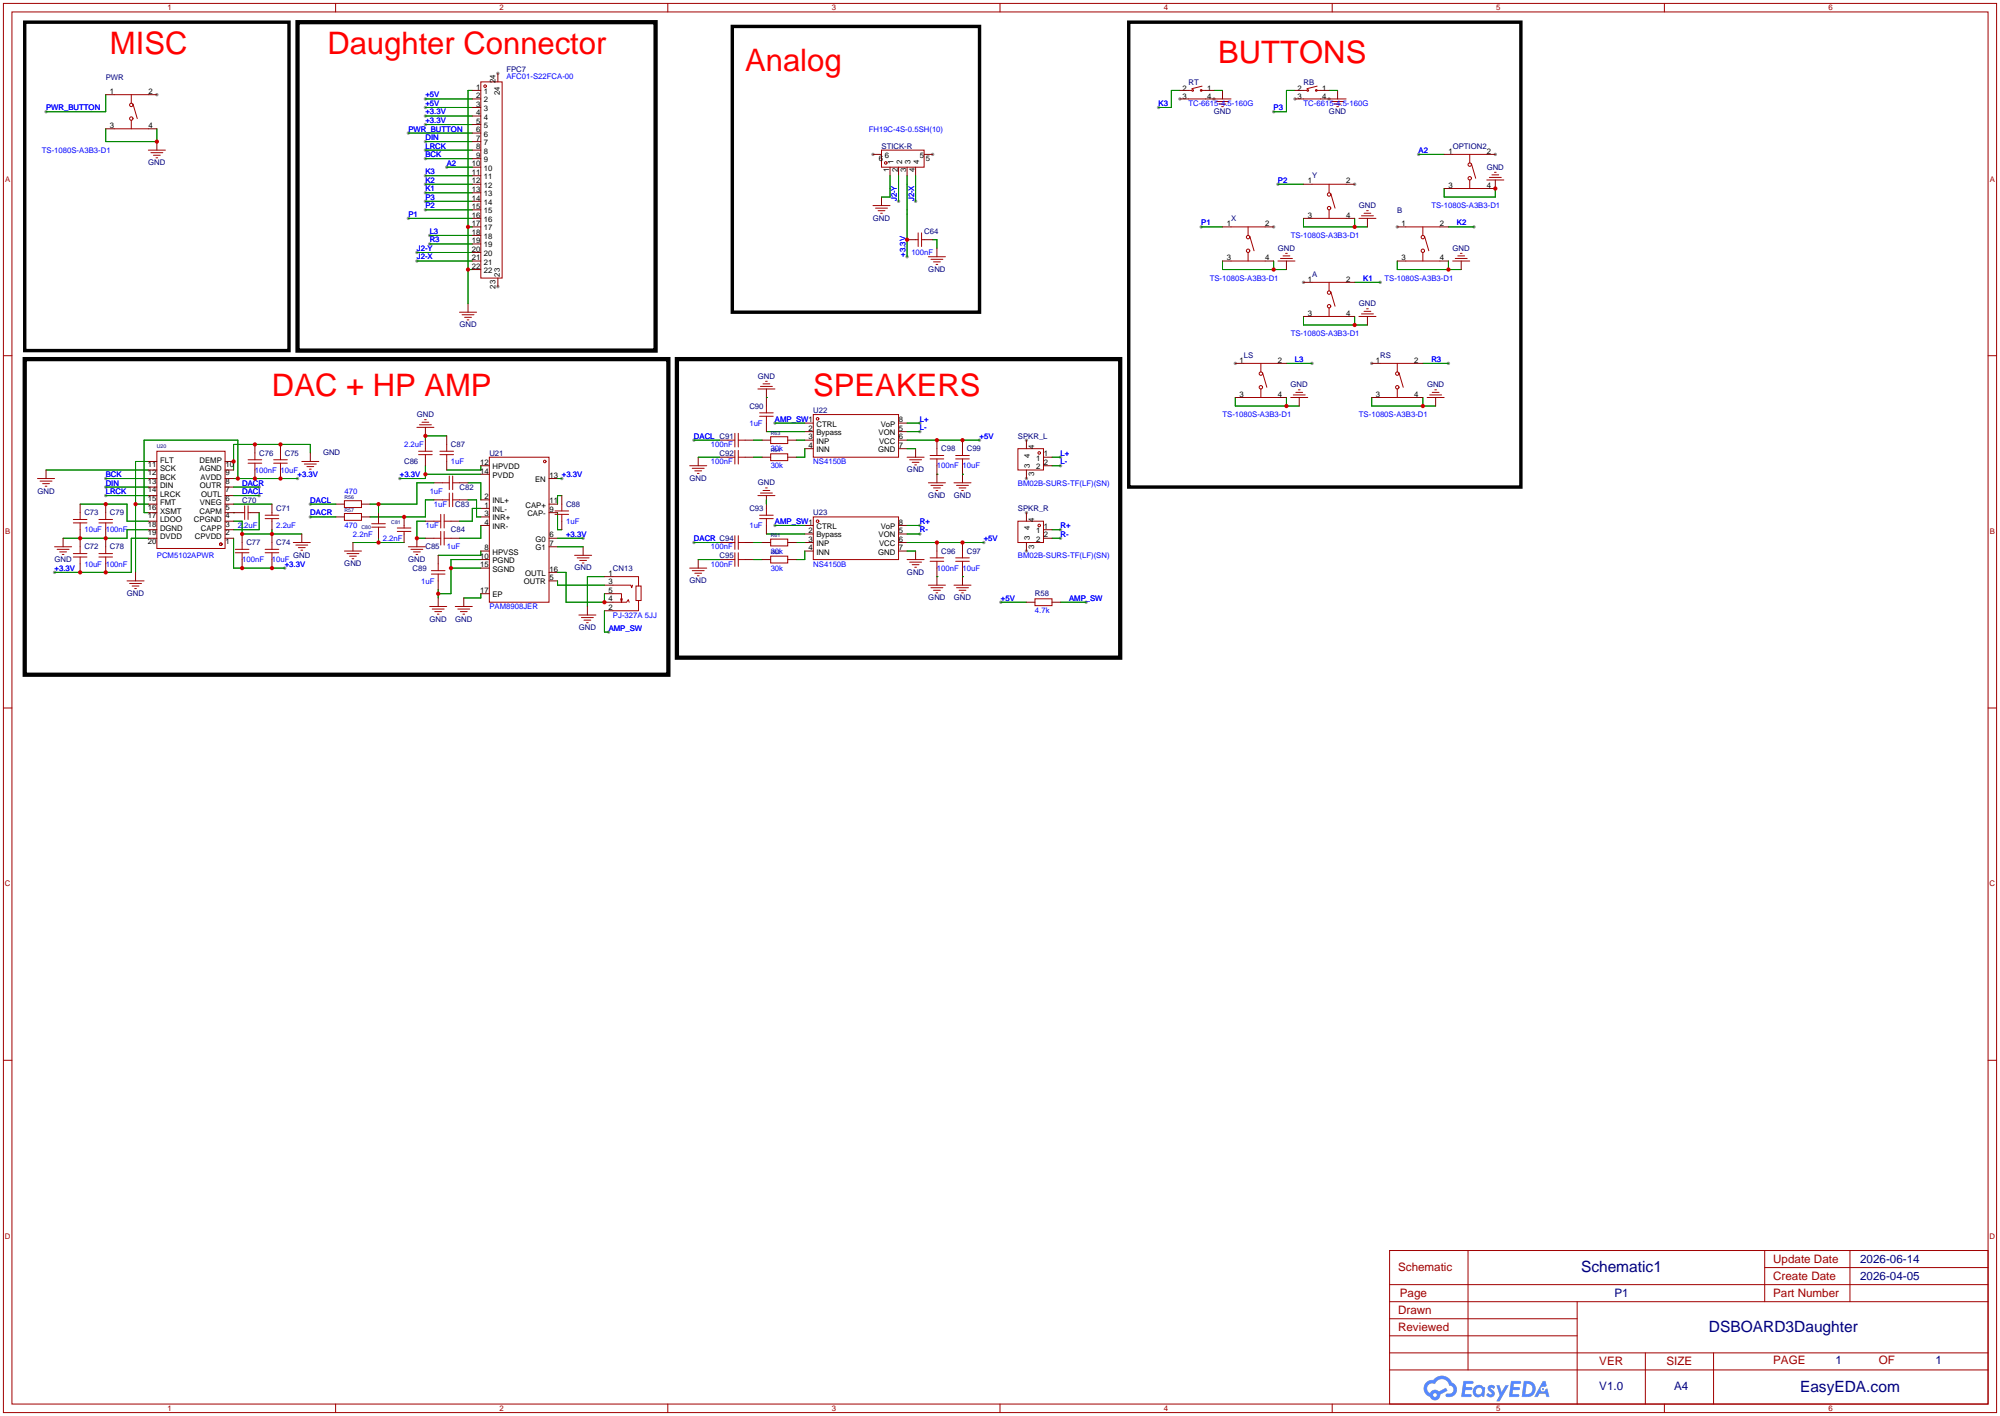
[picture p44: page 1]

DEMP 10 FLT 11 SCK 12 BCK 13 DIN 14 LRCK 15 FMT 16 XSMT 17 LDOO 18 DGND 19 DVDD 20

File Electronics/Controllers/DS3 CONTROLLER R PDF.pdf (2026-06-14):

MCU (rp2040) | FLASH
Mainboard Connector | 3V3 Pwr

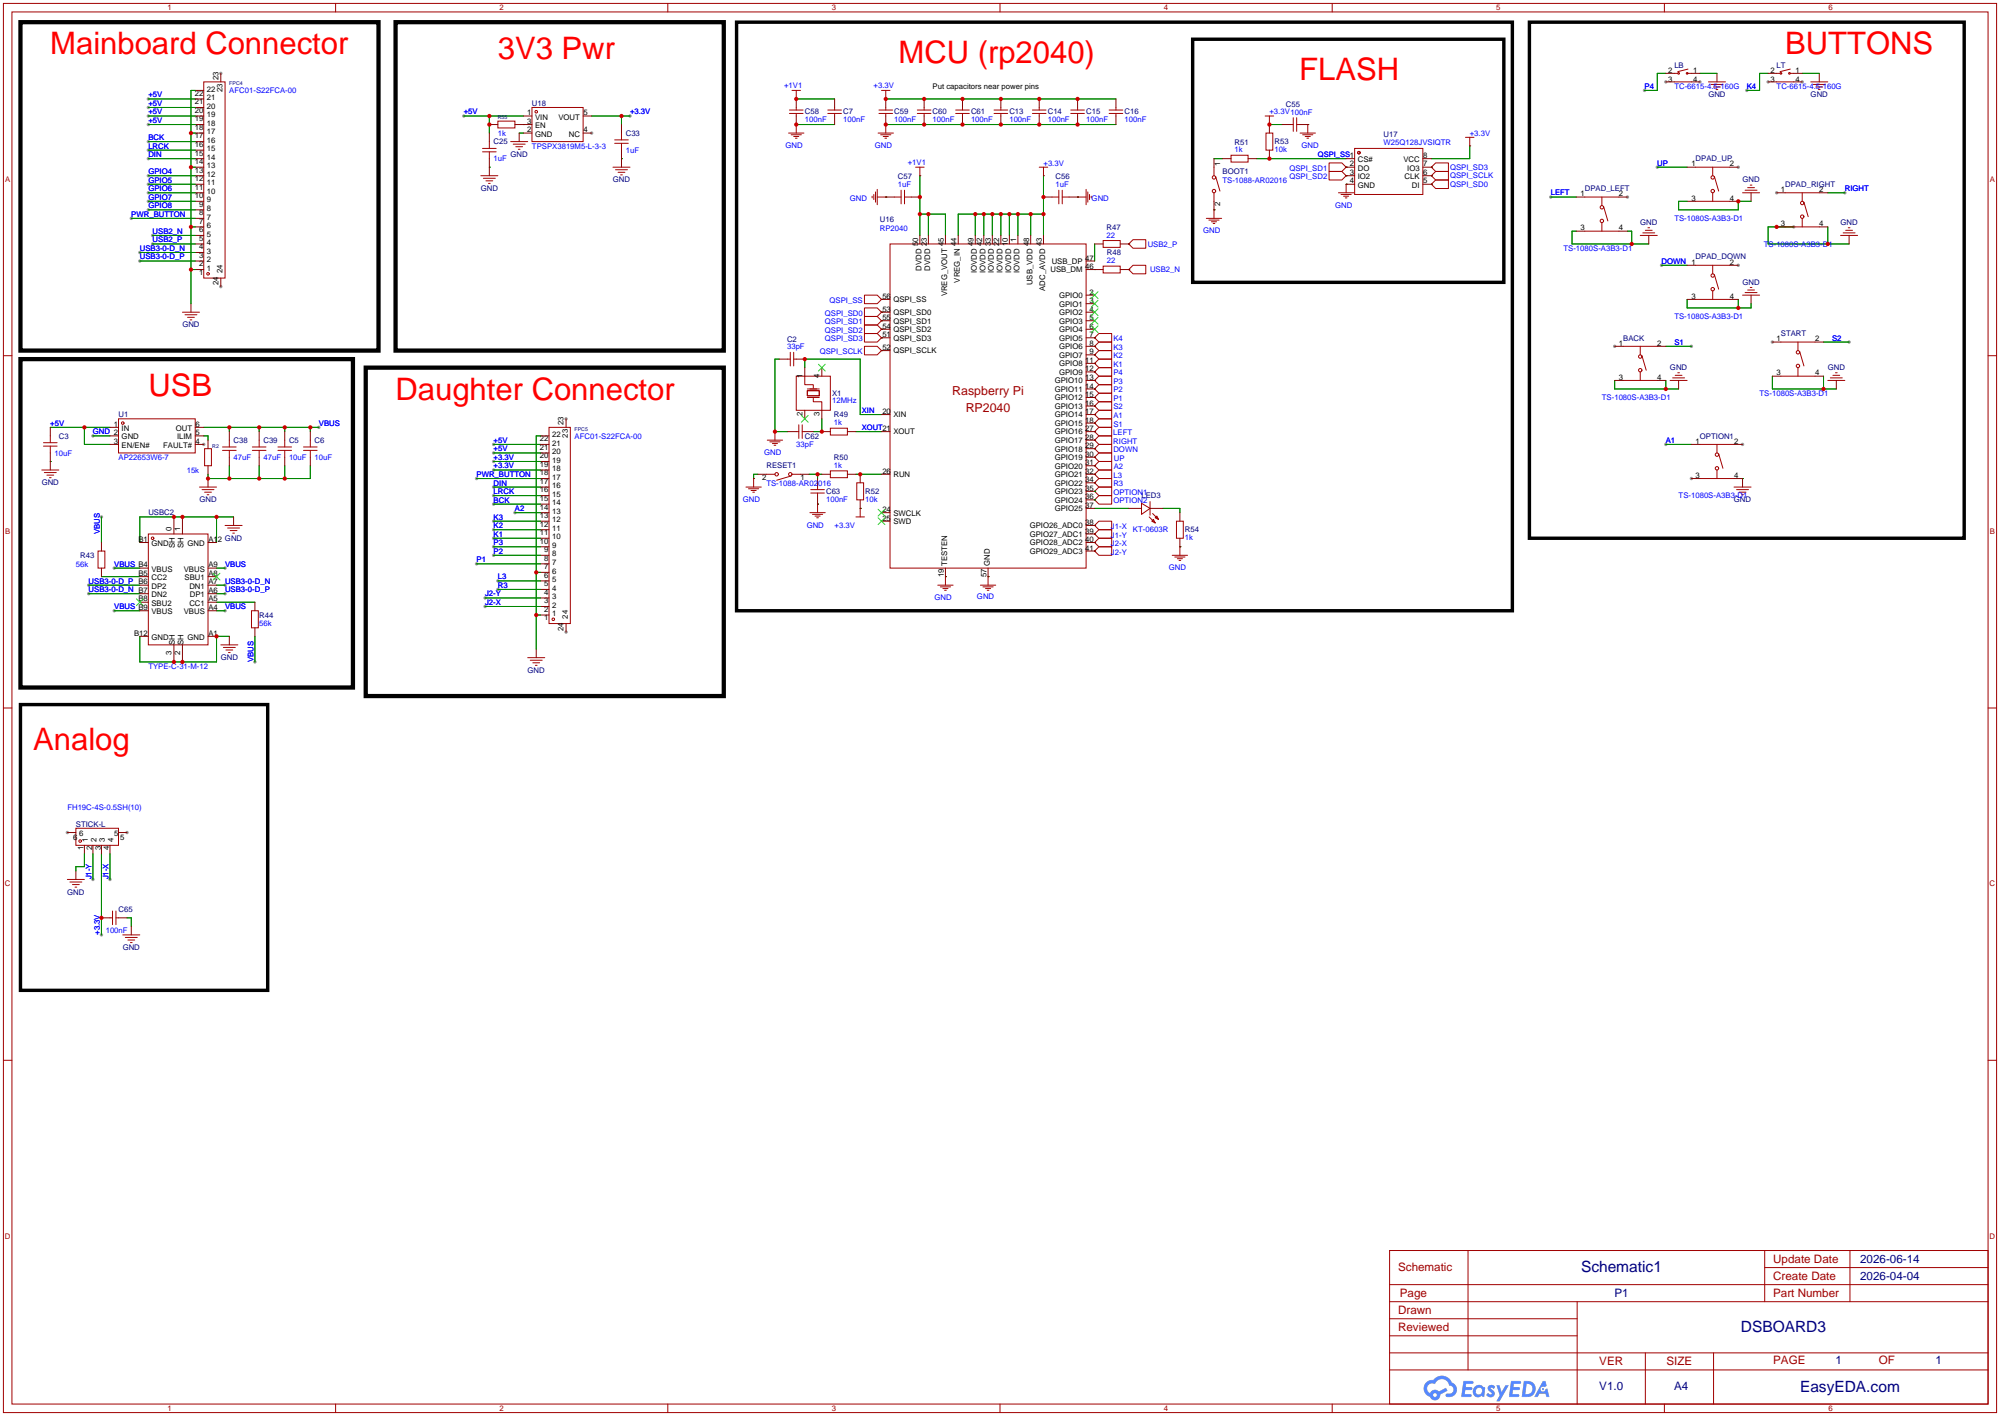
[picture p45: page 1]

Put capacitors near power pins

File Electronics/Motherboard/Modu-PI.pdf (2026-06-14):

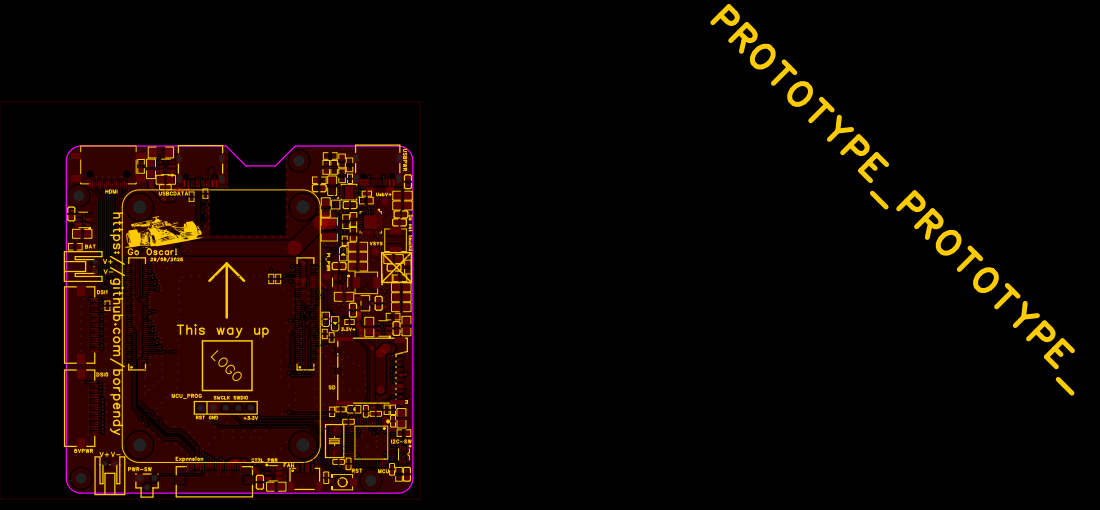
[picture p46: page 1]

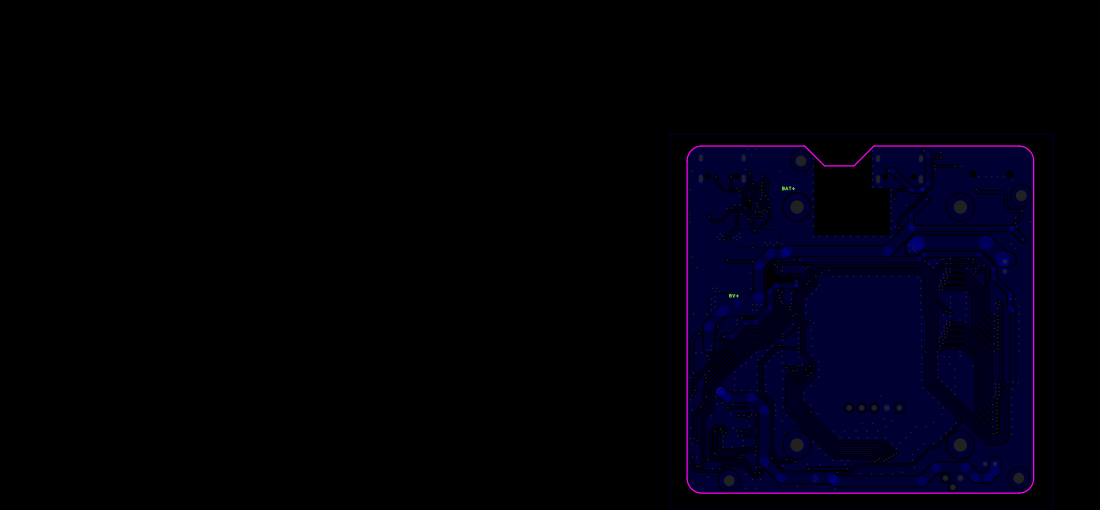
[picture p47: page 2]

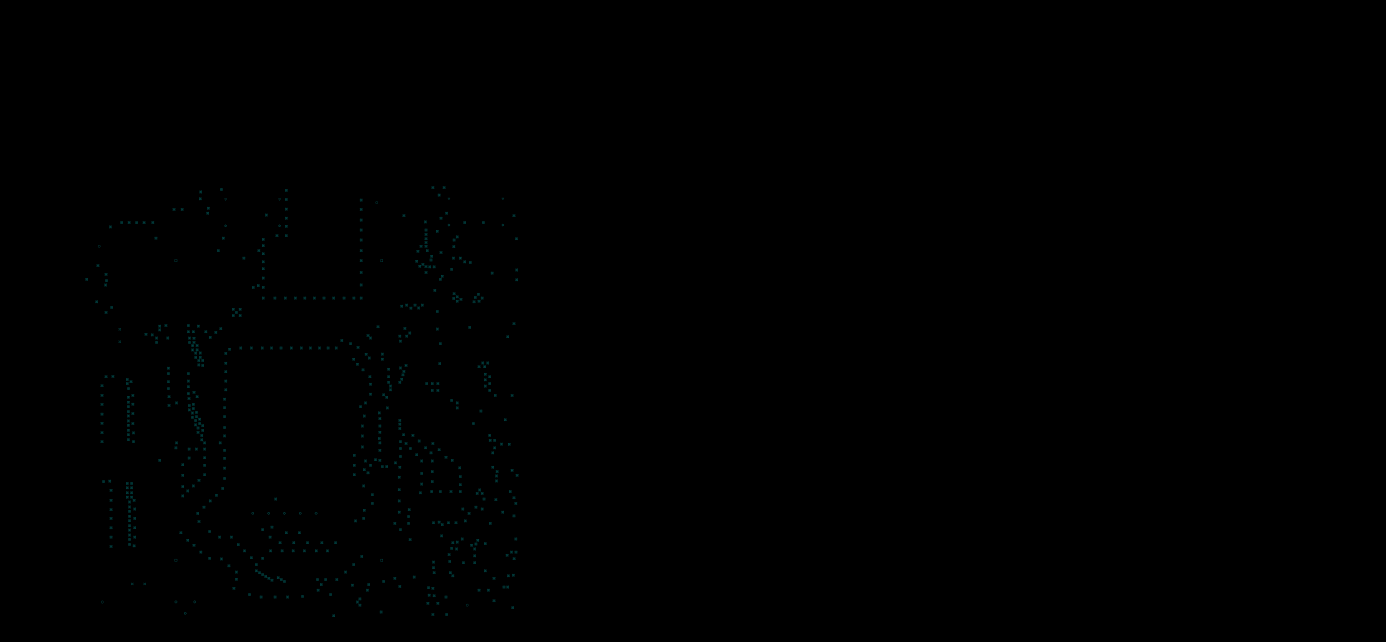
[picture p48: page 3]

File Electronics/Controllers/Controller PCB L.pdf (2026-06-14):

L

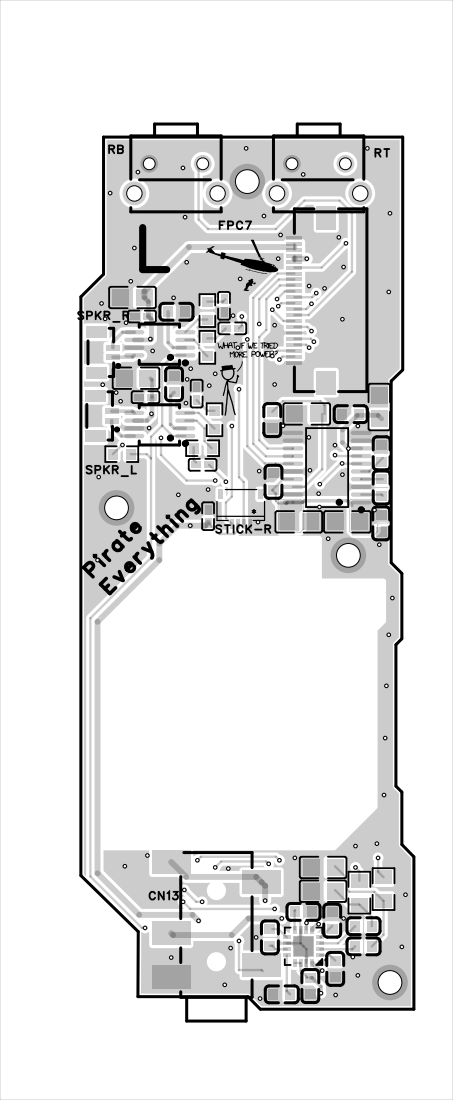
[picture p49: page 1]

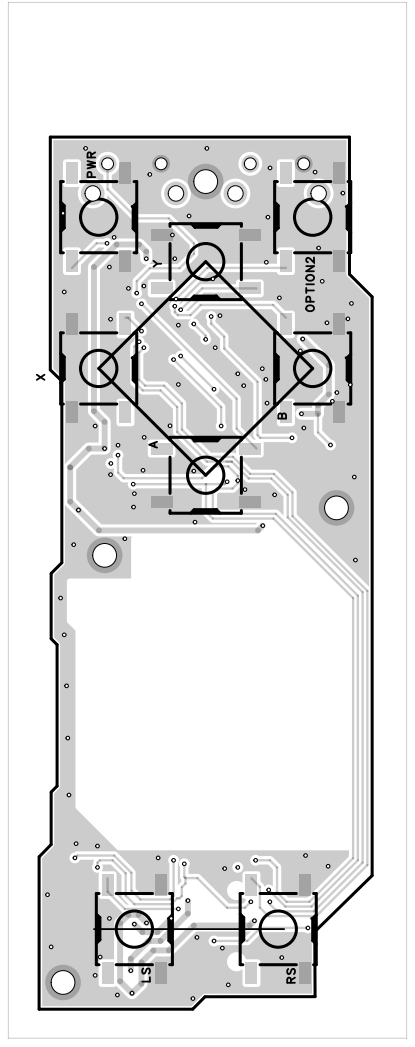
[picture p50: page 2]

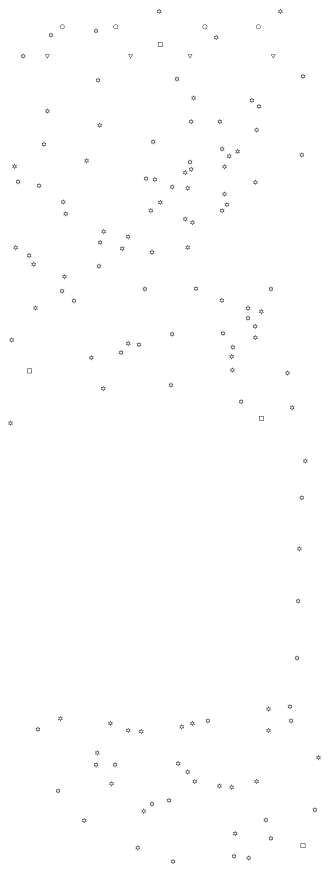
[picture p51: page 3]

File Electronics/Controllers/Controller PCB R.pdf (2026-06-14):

R

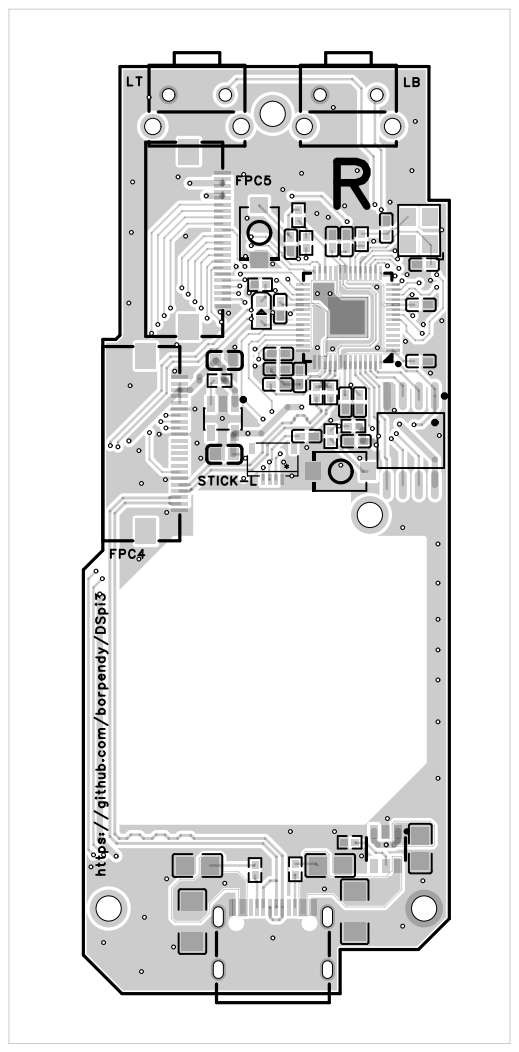
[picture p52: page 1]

https://github.com/borpendy/DSpi3

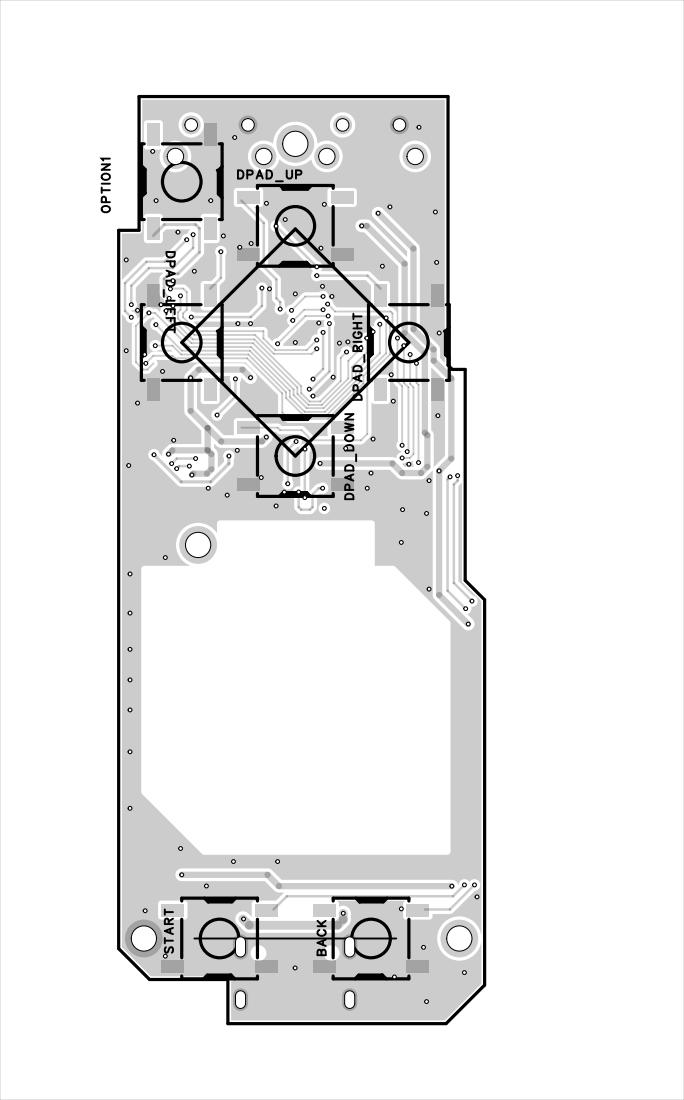
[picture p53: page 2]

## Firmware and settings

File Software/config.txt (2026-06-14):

# For more options and information see
# http://rptl.io/configtxt
# Some settings may impact device functionality. See link above for details

# Uncomment some or all of these to enable the optional hardware interfaces
#dtparam=i2c_arm=on
#dtparam=i2s=on
#dtparam=spi=on

# Enable audio (loads snd_bcm2835)
#dtparam=audio=on

# Additional overlays and parameters are documented
# /boot/firmware/overlays/README

# Automatically load overlays for detected cameras
camera_auto_detect=1

# Automatically load overlays for detected DSI displays
display_auto_detect=1

# Automatically load initramfs files, if found
auto_initramfs=1

# Enable DRM VC4 V3D driver
dtoverlay=vc4-kms-v3d
max_framebuffers=2

# Don't have the firmware create an initial video= setting in cmdline.txt.
# Use the kernel's default instead.
disable_fw_kms_setup=1

# Run in 64-bit mode
arm_64bit=1

# Disable compensation for displays with overscan
disable_overscan=1

# Run as fast as firmware / board allows
arm_boost=1

[cm4]
# Enable host mode on the 2711 built-in XHCI USB controller.
# This line should be removed if the legacy DWC2 controller is required
# (e.g. for USB device mode) or if USB support is not required.
otg_mode=1

[cm5]
dtoverlay=dwc2,dr_mode=host

[all]
dtoverlay=vc4-kms-dsi-waveshare-panel-v2,5_0_inch_a
#DSI0 Use
dtoverlay=vc4-kms-dsi-waveshare-panel-v2,5_0_inch_a,dsi0
dtoverlay=hifiberry-dac
